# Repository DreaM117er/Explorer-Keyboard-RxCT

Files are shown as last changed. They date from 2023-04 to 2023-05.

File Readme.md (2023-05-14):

# Explorer Keyboard RxCT 探索者1號

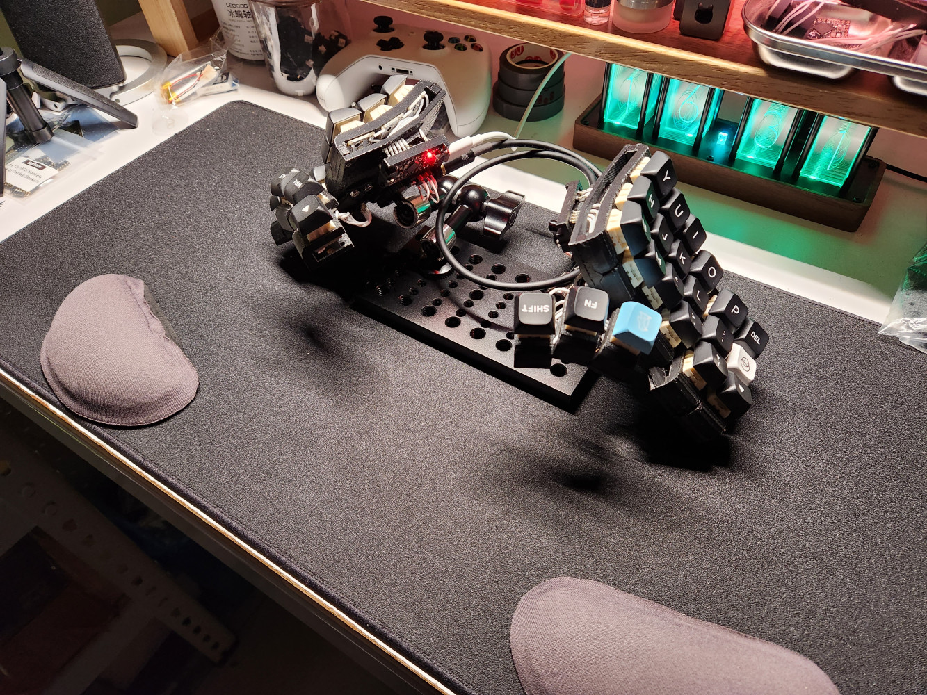
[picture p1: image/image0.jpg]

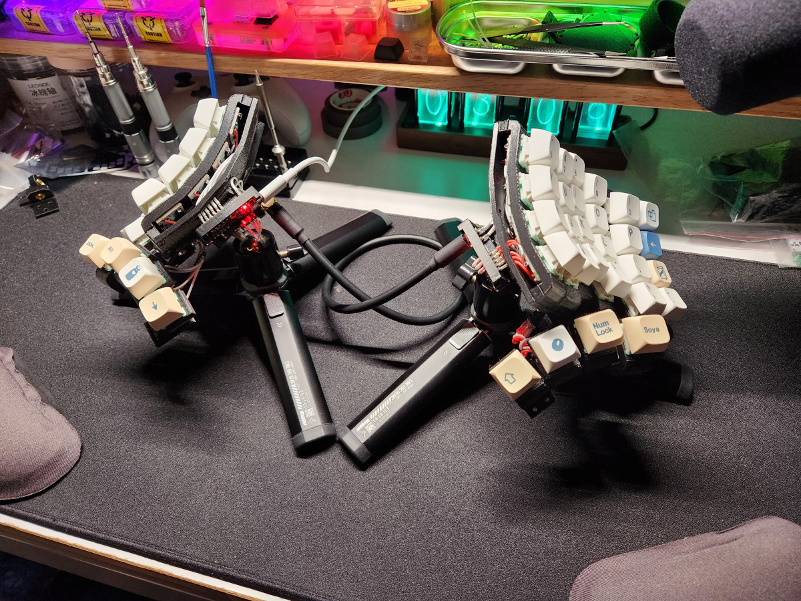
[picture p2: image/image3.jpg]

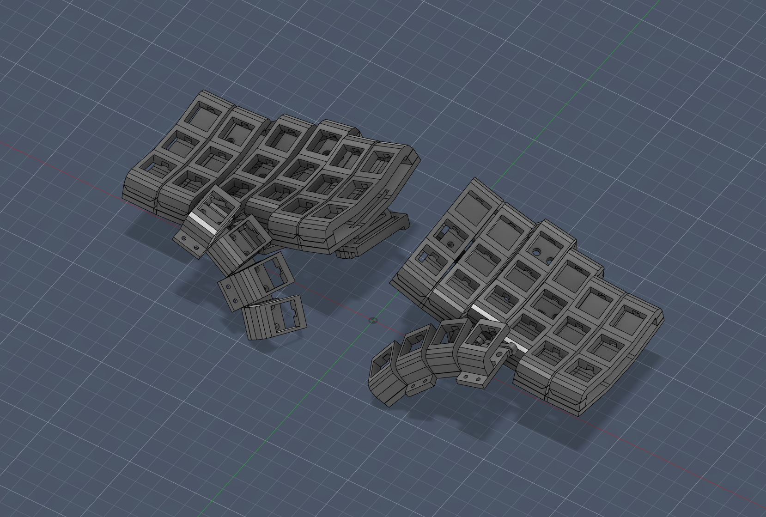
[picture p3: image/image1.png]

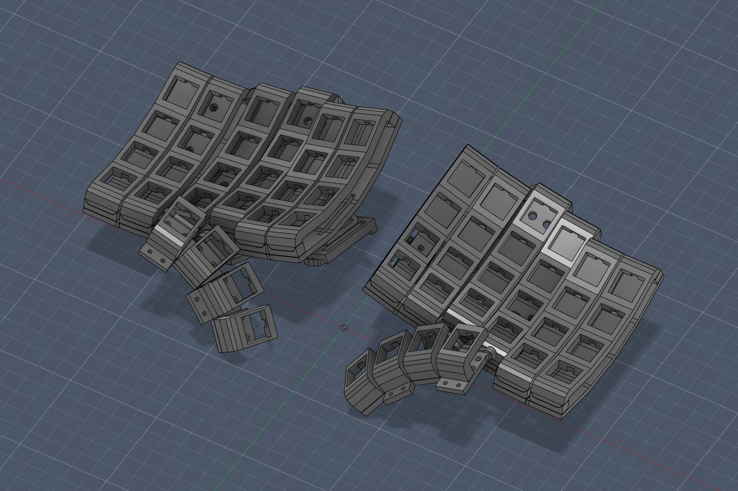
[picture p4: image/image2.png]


## 簡介

RxCT是基於[Dactyl Manuform](https://github.com/abstracthat/dactyl-manuform)家族中的5x6、[Skeleton Edition](https://github.com/atsuyuki/dactyl-manuform-skeleton-edition-4x5)及[Bastardkb TBKmini](https://github.com/Bastardkb/TBK-Mini)這三把分離式鍵盤設計，其特點在於使用相機雲台作為主要固定方式，以3x5及4x5為鍵盤主配列，可向外側拓展1排按鍵，將鍵盤配列變更為3x6及4x6；拇指區基礎為1-4顆按鍵設計，可依據底板連接器橋接拇指區的每顆按鍵，再根據連接主鍵盤的基座，微調拇指區角度的分離式機械鍵盤。

## 特色

- 直列定位板、拇指按鍵模組化設計
- 可調整整體角度的拇指區
- 拇指最外側及最內側定位板可2檔微調
- 主要雲台安裝位於底殼，可外掛插件將雲台安裝在前端

## 組裝及操作說明

- [組裝說明書](guide.md) 
- [操作說明書](manual.md)
- 無線安裝說明（開發中）

## 構造

- 底殼（3x5及4x5基礎大小）
- 拓展板（3x1及4x1）
- 框架（3x5、4x5及拓展1x1）
- 直列定位板（3x1及4x1）
- 拇指區基座
- 拇指定位板
- 拇指底板（2片可接基座、2片純拓展）
- 拇指底板連接器
- 主控座（可安裝TRRS、純MCU）
- 電池倉（2050規格聚合物鋰電池，3種厚度）
- 前方雲台插件

## 構造圖

- 底殼、拓展板
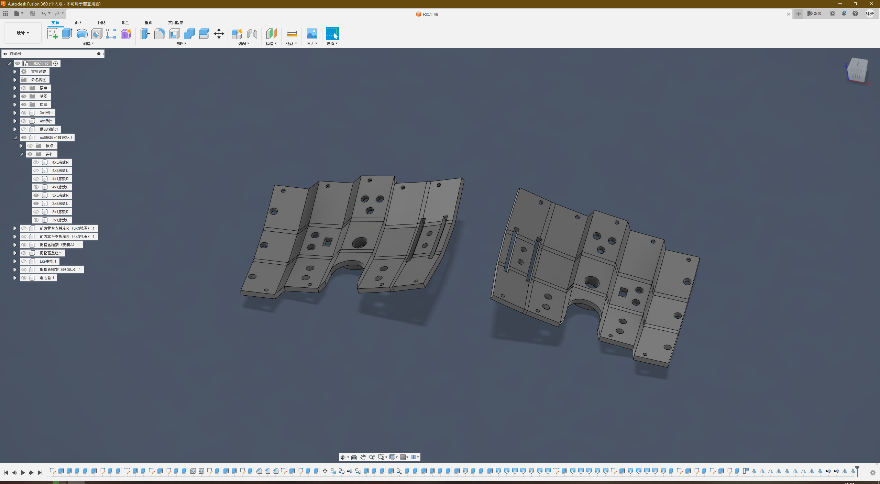
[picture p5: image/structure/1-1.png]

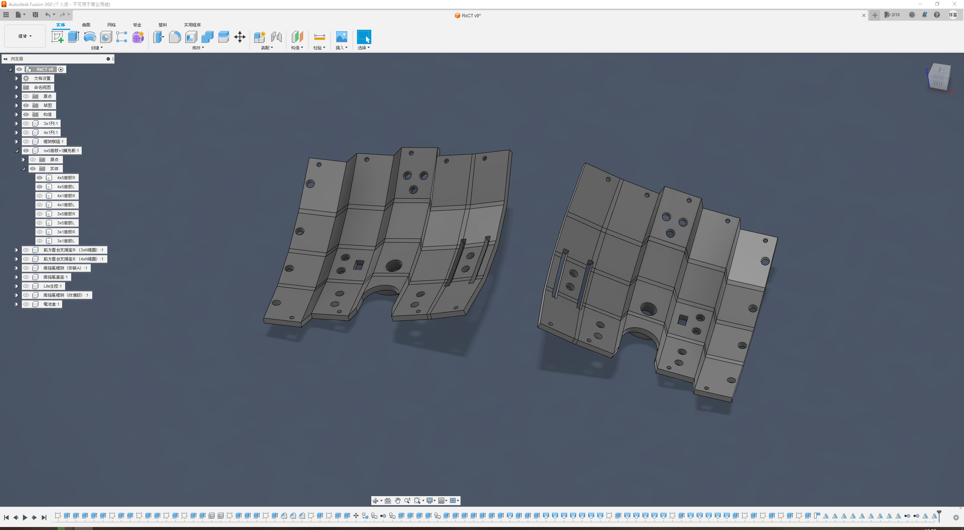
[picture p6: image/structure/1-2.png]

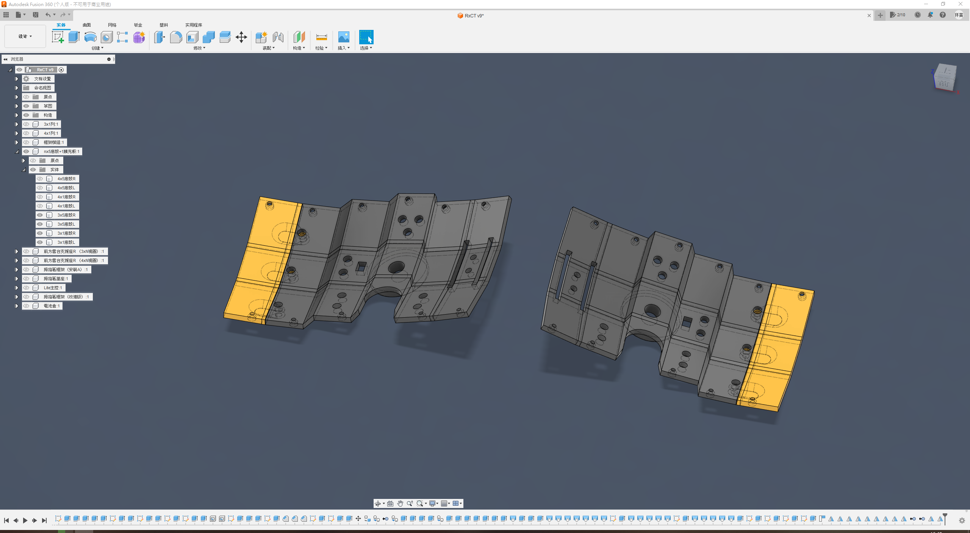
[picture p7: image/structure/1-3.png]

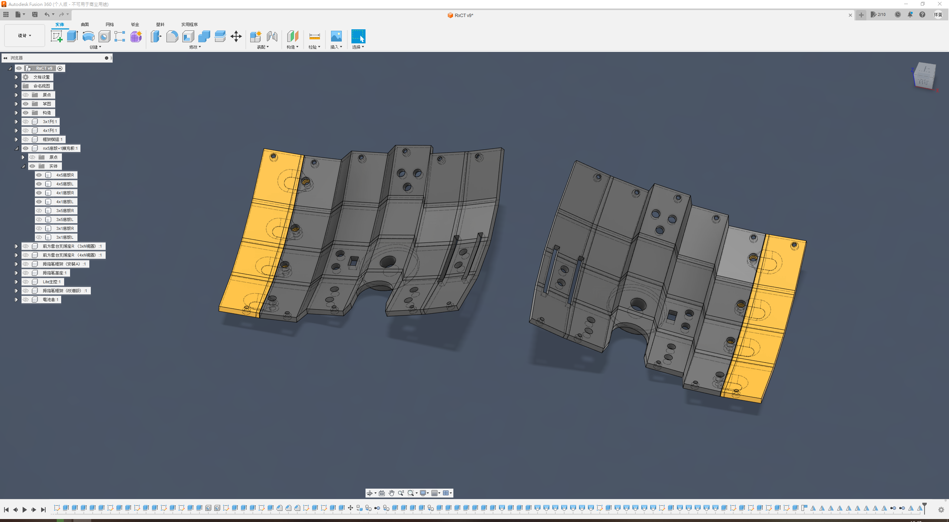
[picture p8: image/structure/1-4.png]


- 框架
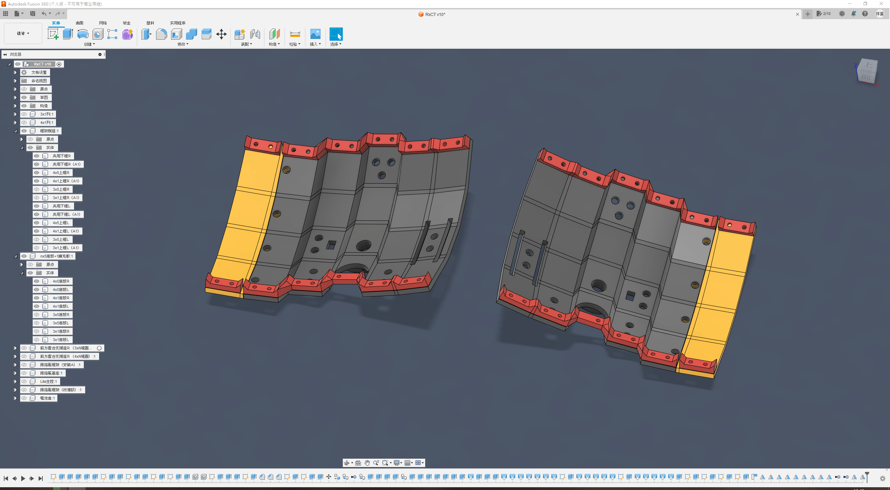
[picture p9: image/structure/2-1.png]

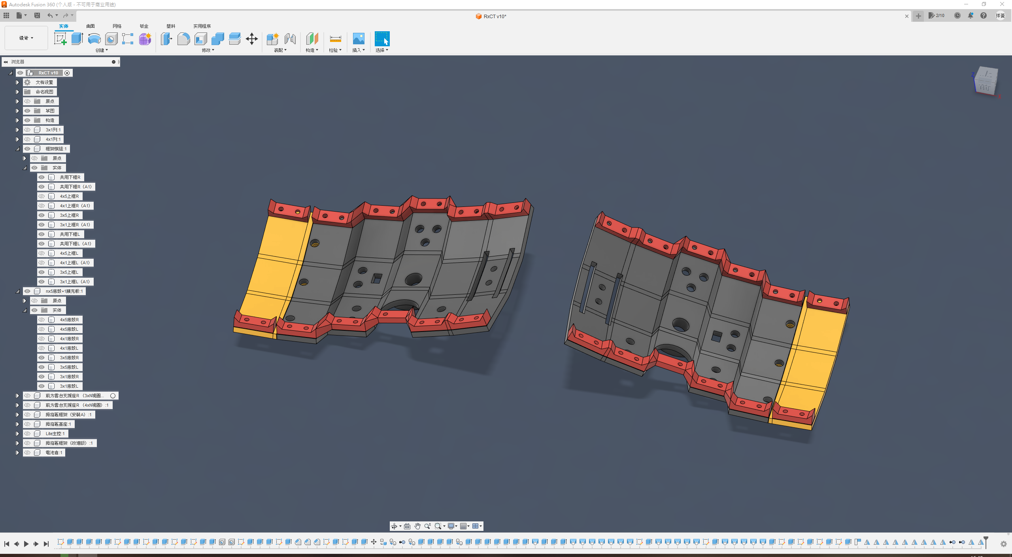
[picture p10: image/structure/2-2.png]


- 直列定位板
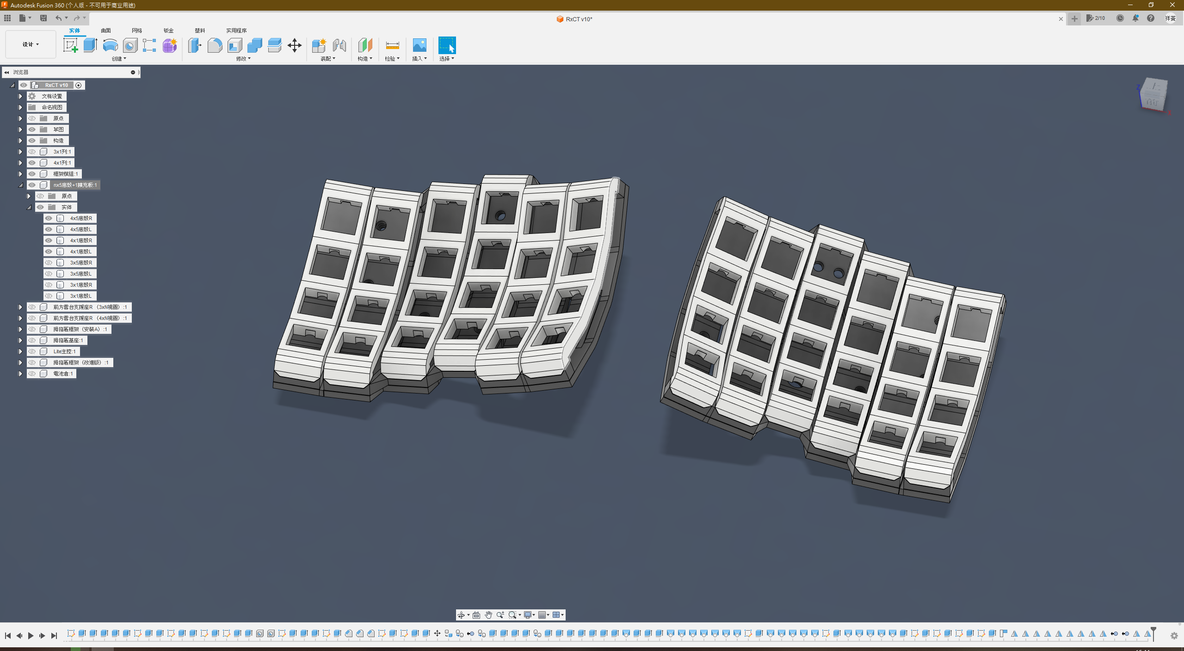
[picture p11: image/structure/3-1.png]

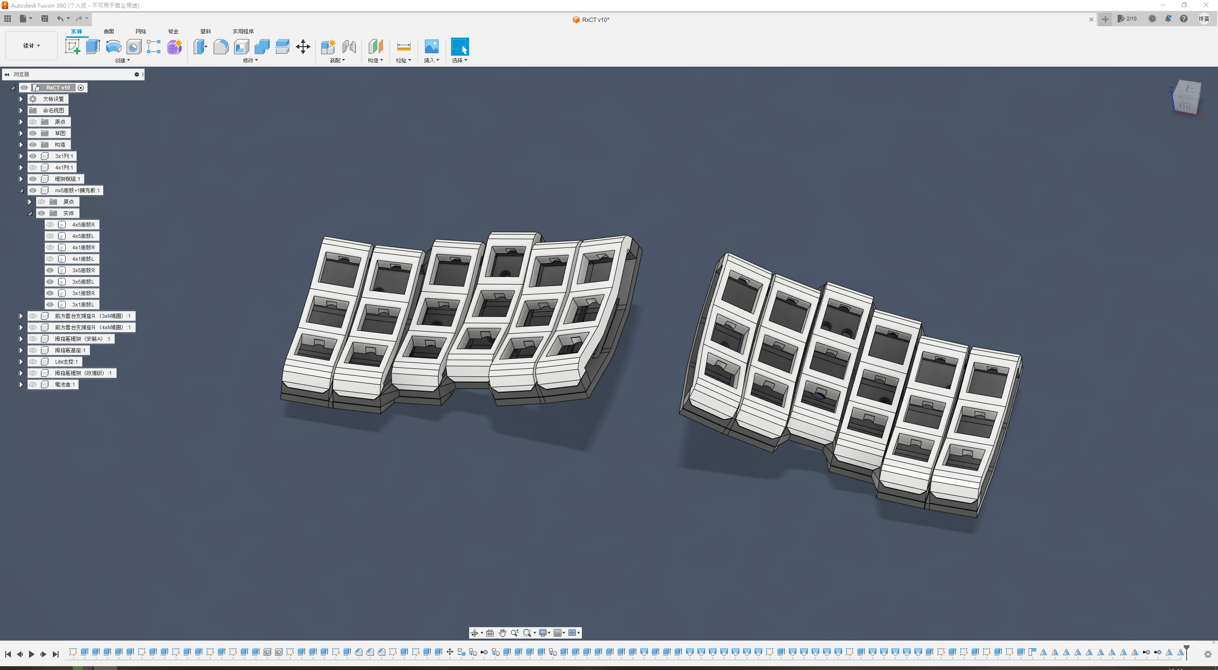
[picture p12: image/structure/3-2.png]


- 拇指區基座
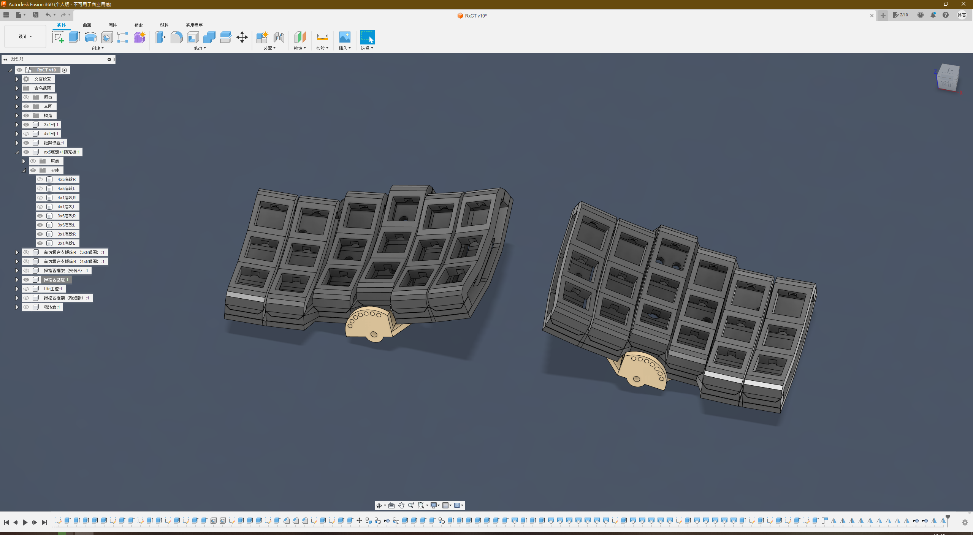
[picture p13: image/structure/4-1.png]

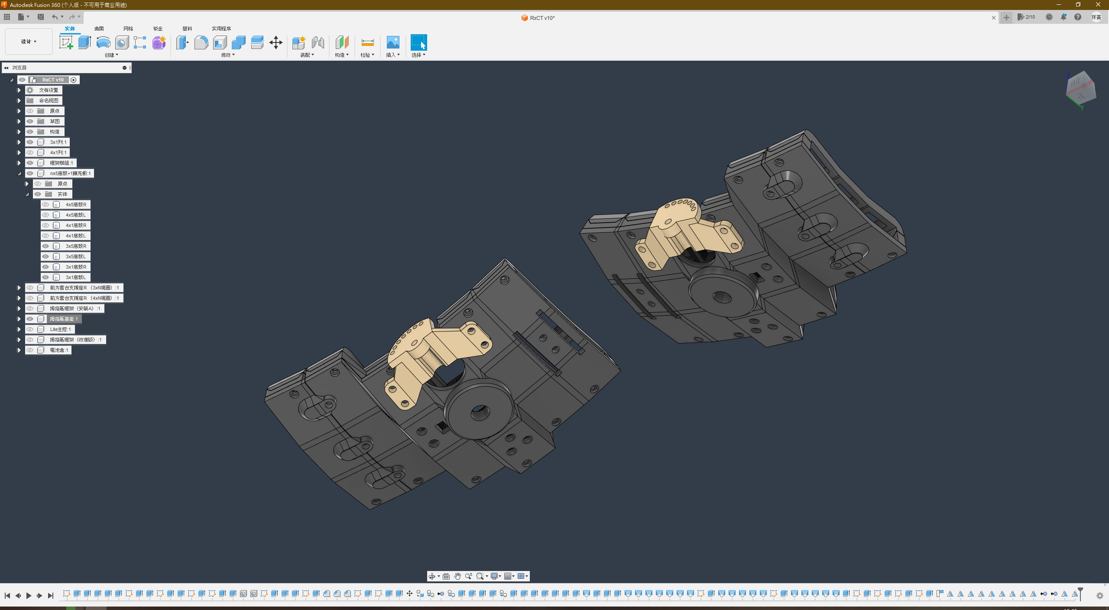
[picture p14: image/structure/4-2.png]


- 拇指定位板、拇指底板、連接器
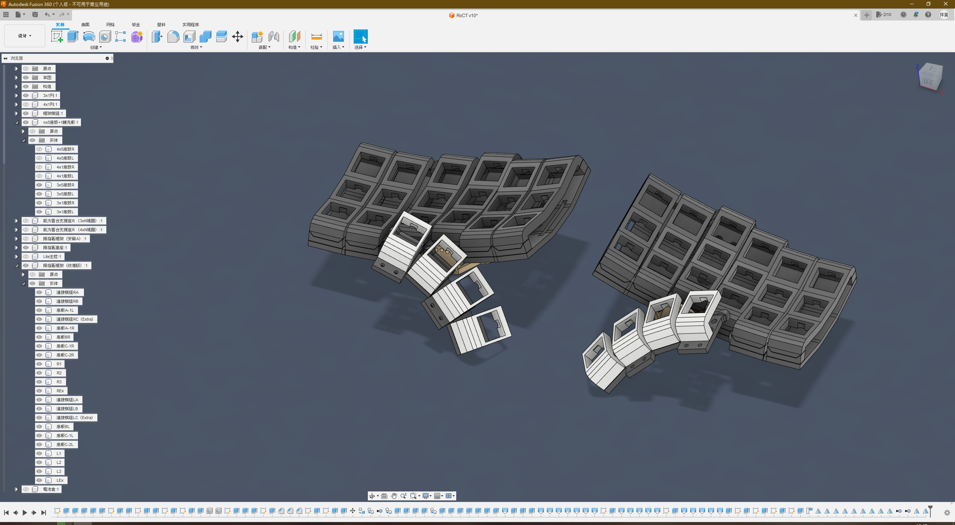
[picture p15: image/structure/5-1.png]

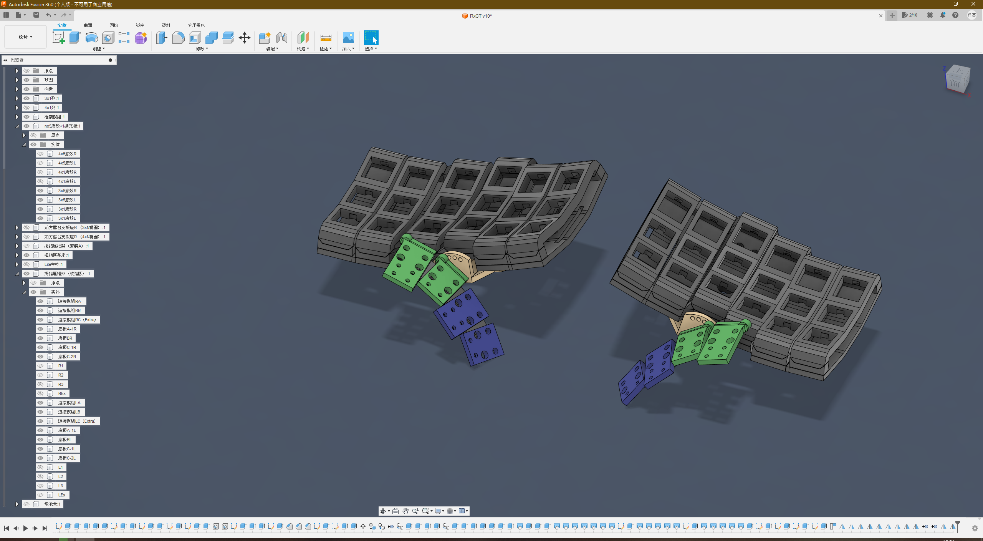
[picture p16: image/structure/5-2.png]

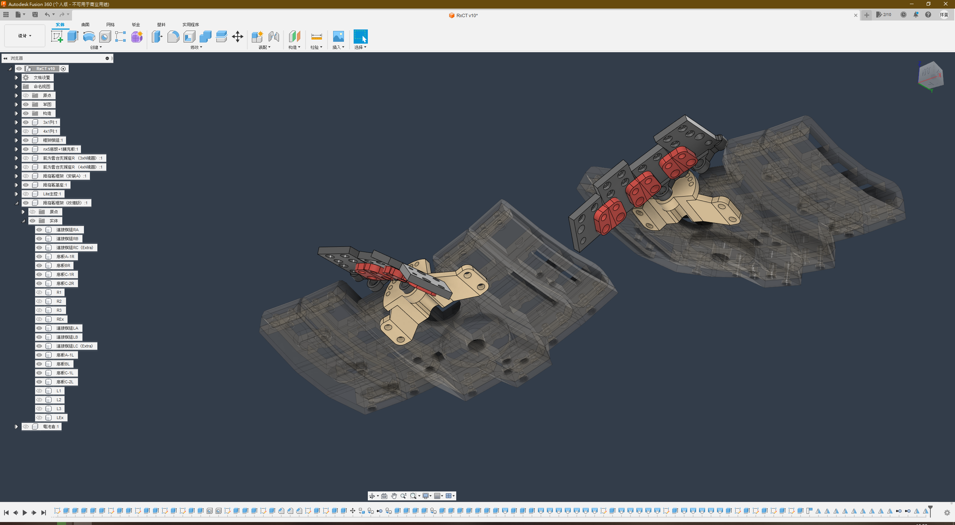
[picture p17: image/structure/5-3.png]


- 主控座、電池倉
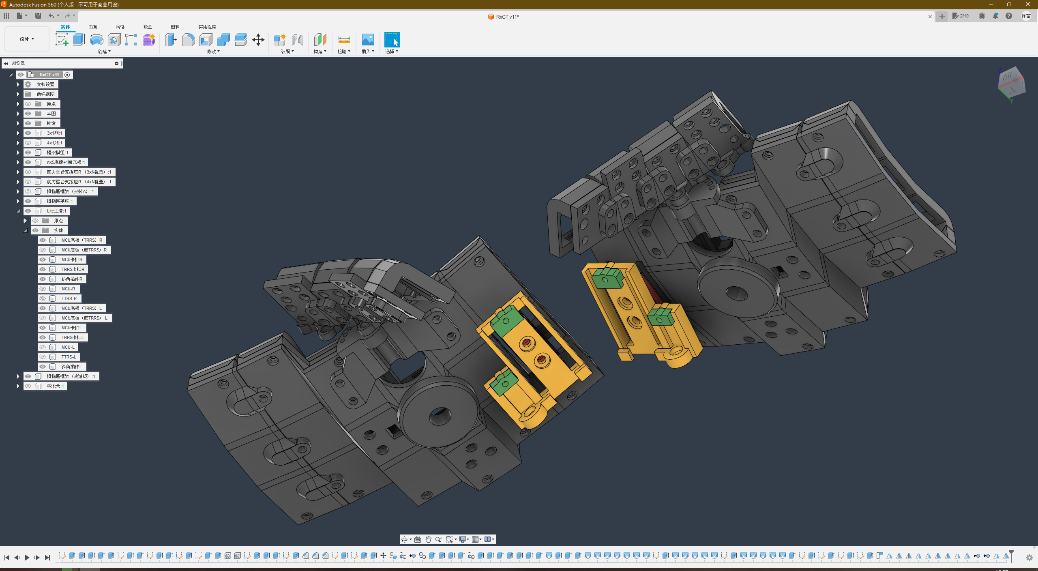
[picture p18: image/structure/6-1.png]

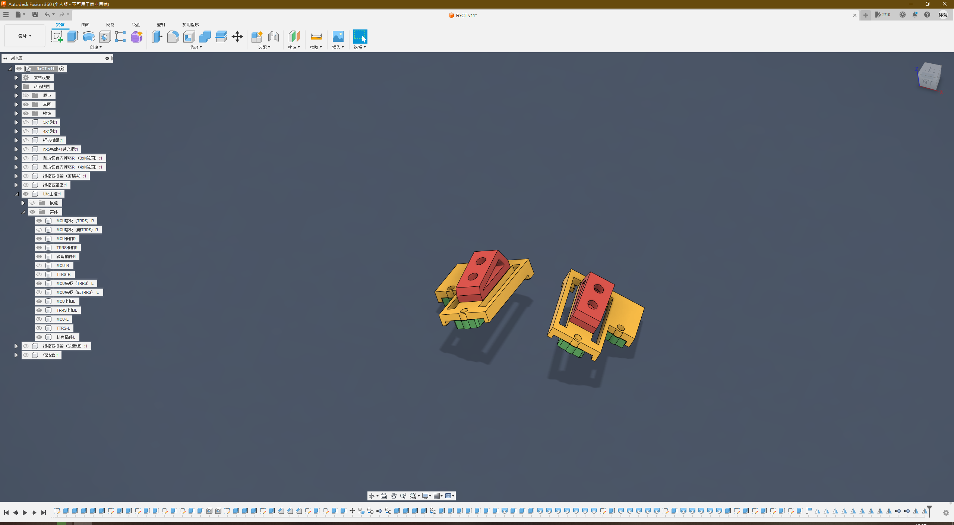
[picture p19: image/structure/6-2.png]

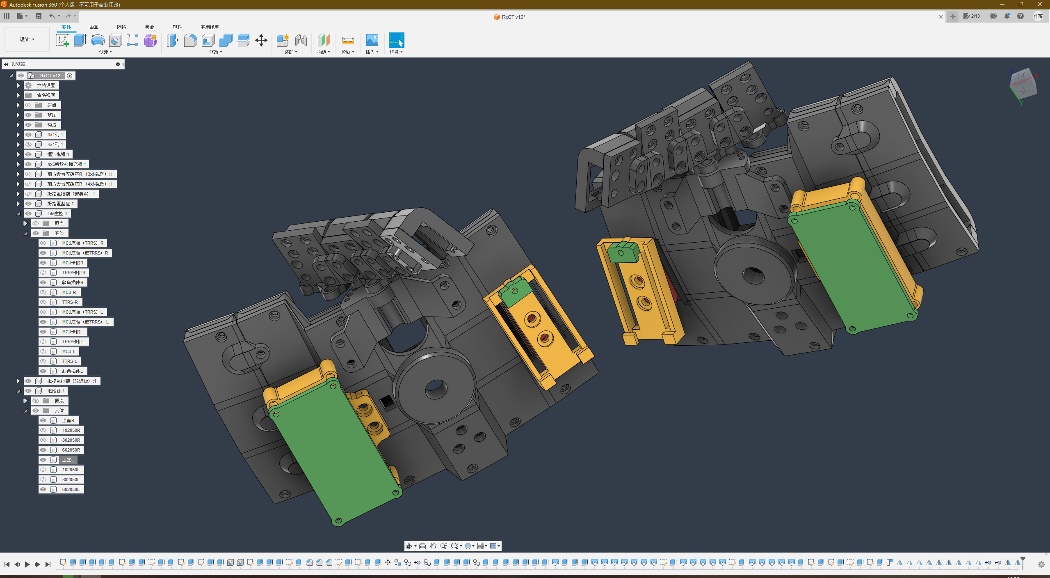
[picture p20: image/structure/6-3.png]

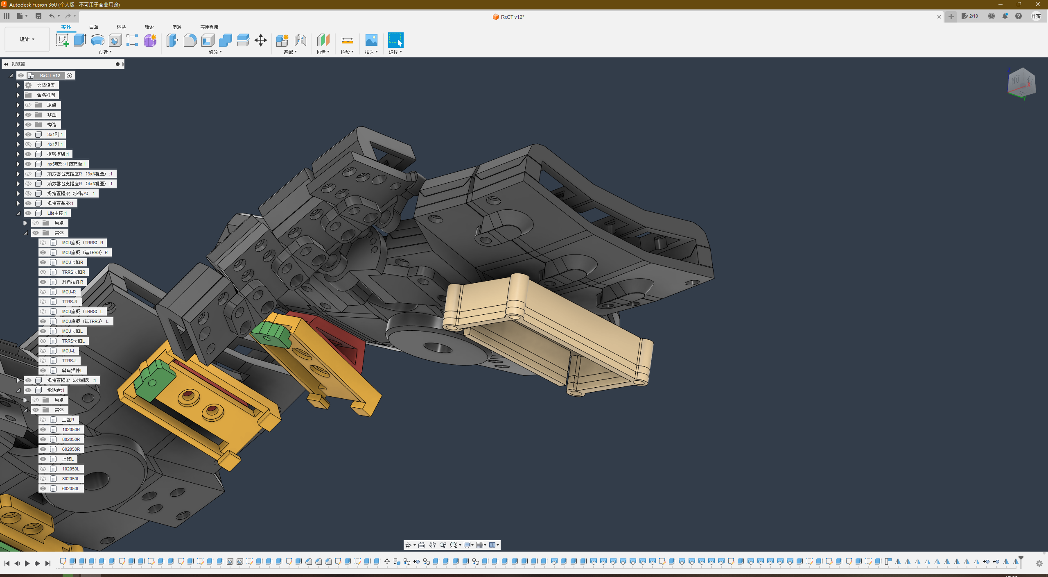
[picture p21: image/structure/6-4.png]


- 前方雲台插件
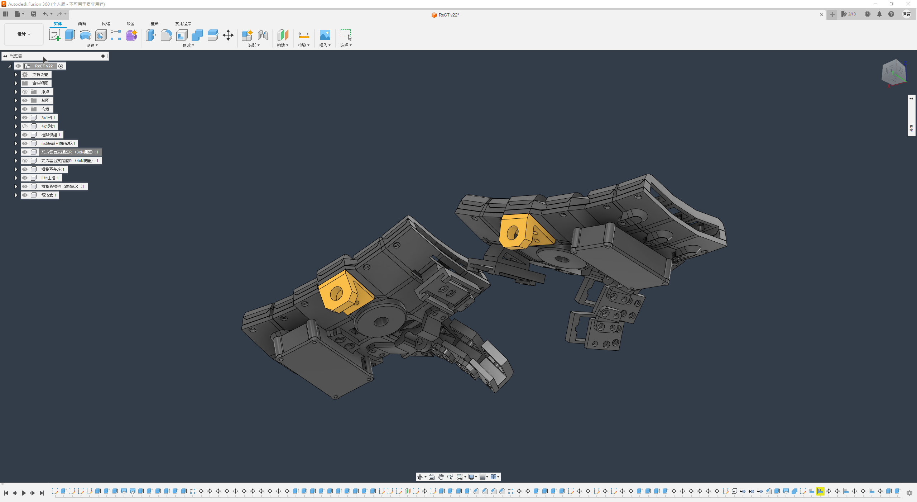
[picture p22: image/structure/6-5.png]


## 特別感謝

- [Pragmatic務實鍵盤](https://github.com/jamessa/Pragmatic)及開發者[James Sa](https://github.com/jamessa)，在3D設計、3D列印、韌體代碼、[人體工學邏輯](https://www.youtube.com/watch?v=p7gZdOTpbP8)上的指導。
- [務實鍵盤官方網站](https://www.pragmatic.com.tw/)
- [Bastardkb](https://bastardkb.com/?fbclid=IwAR0HTUxLdHe8ZL2sCDtqDt270YRag5GlEKGHjyKge5UxckXjq_M7VrpKhu0) [TBKmini](https://bastardkb.com/product/tbk-mini-kit/)、[Dactyl Manuform](https://github.com/abstracthat/dactyl-manuform) 5x6、[Dactyl Manuform Skeleton Edition](https://github.com/atsuyuki/dactyl-manuform-skeleton-edition-4x5)，沒有接觸到你們，也不會有探索者的誕生。
- [KBDnews](https://kbd.news/Explorer-RxCT-1994.html)
- [開發日誌](log.md)

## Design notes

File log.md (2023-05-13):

# 開發日誌

## 開發歷史

- 2022.12.26 正式組裝第一把TBKmini。
- 2023.01.09 正式完成Dactyl Manuform 5x6。
- 2023.01.16 完成第二把TBKmini（完全手拉矩陣），改寫QMK韌體。
- 2023.01.26 正式安裝[Fusion360](https://www.autodesk.com/products/fusion-360/overview?term=1-YEAR&tab=subscription)在個人電腦上。
- 2023.01.31 請James列印的Skeleton Edition入手。
- 2023.02.11 第一款失敗模型設計成品入手。
- 2023.02.28 第二款失敗模型設計成品入手，到03.07才知道它也是失敗模型。
- 2023.03.08 探索者第一版雛形成品完成。
- 2023.03.14 探索者第二版模型完成。
- 2023.03.22 探索者Prototype單手模型完成。
- 2023.04.01 探索者正式命名為系列，3x6+3鍵盤完成、測試。
- 2023.04.15 正式命名RxCT為探索者1號。
- 2023.04.23 探索者1號檔案Github正式開源。
- 2023.04.24 探索者1號登上[KBDNews](https://kbd.news/Explorer-RxCT-1994.html)。
- 2023.05.06 支援探索者1號的[VIAL](https://get.vial.today/)韌體完工。
- 2023.05.10 探索者1號的[韌體](https://github.com/DreaM117er/Explorer-Keyboard-RxCT/releases)正式發佈。
- 2023.05.14 探索者1號4x6+4鍵盤完成、測試。

## 開發心得

探索者1號的開發大約花了一個半至兩個月的時間，很多人會認為一把這樣需要調整這麼多參數的分離式機械鍵盤需要花相當多的時間去完成，通常大部分人認知是這樣沒有錯。但這真的是事實，我在2023年1月26日正式在我個人的電腦上安裝[Fusion360](https://www.autodesk.com/products/fusion-360/overview?term=1-YEAR&tab=subscription)，安裝AutoDesk這款工程3D軟體的時候，我連3D繪圖都不了解。

沒有錯，我是個3D繪圖基礎都沒有的新手，對於自己設計分離式鍵盤來說，這毫無疑問是相當大地挑戰，前前後後自己找了網路資源慢慢學習，學了一個步驟之後就直接開軟體實作，實作的對象就直接是鍵盤本體。

真的要說我失敗了幾次嘛... 也有20次以上了，實際加上James協助我做3D列印的服務的時候都要謹慎，不是所有設計出來的東西都是可以100%列印成功的，即便成功好了，實際模型是不是可以運作也是一大課題；嚴格來說James協助我做3D列印服務，我們雙方也是買賣關係，僅在設計鍵盤方面有著相同的背景及興趣，我真的很感謝他，讓我這個瘋子能夠順利地完成這把鍵盤。

## 設計理念

從我開始入手使用分離式人體工學鍵盤後，就發現每把鍵盤都有1個到2個我覺得是缺點的地方，打個比方：

- [Corne](https://github.com/foostan/crkbd)的拇指區，最內側的按鍵真的是相當地難按，而且相當不舒適。
- [TBKmini](https://github.com/Bastardkb/TBK-Mini)則是中指太過下凹，導致我在移動食指中指的時候非常容易卡到鍵帽。
- [TBKmini](https://github.com/Bastardkb/TBK-Mini)後來經過James的指導後發現拇指區正常擺放時也會有傷害到手指的疑慮，觀察過後真的是如此。
- [Skeleton Edition](https://github.com/atsuyuki/dactyl-manuform-skeleton-edition-4x5)原本會是我的下一把鍵盤，但礙於沒有3x6+3的配列，也就成為我開始設計鍵盤的主因之一。
- [Dactyl Manuform](https://github.com/abstracthat/dactyl-manuform)則是體積太大，底座太高，不然它真的相當舒適。

綜合起來歸納出來幾點是我想改進的：

- 長得像TBKmini的3x6+3，合計42鍵的鍵盤。
- 根據使用鍵盤時手指正常移動的軌跡後發現需要讓中指區跟食指、無名指區域齊平。

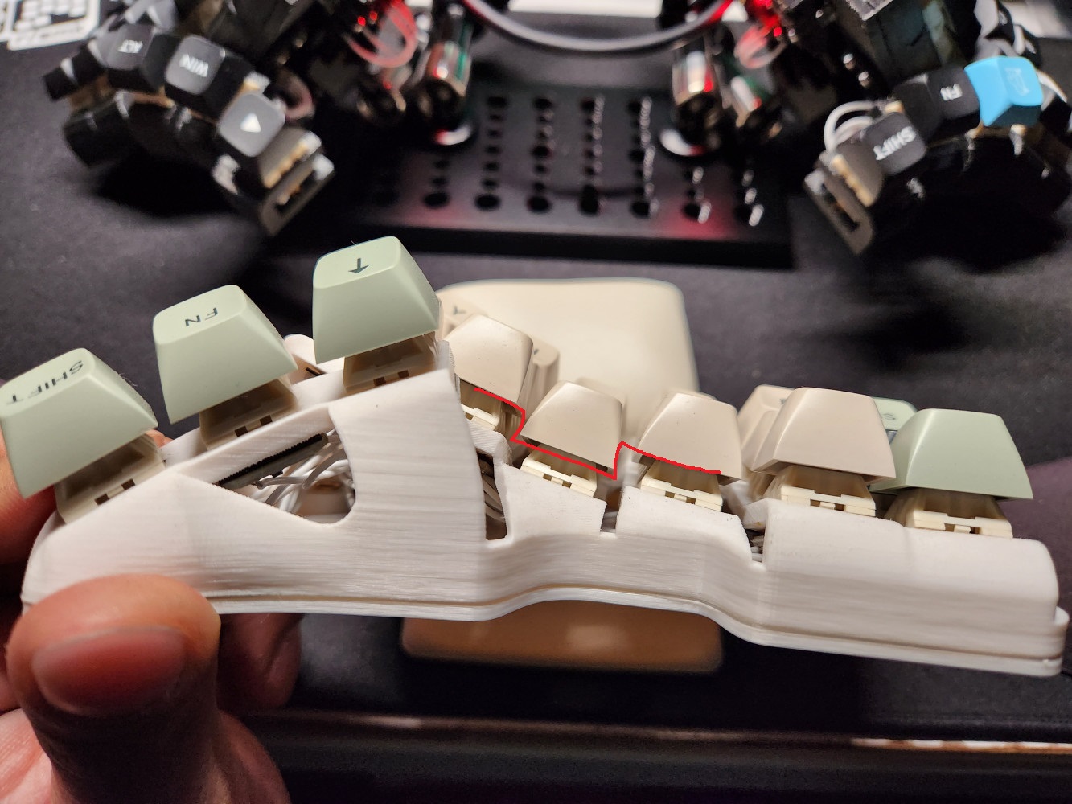
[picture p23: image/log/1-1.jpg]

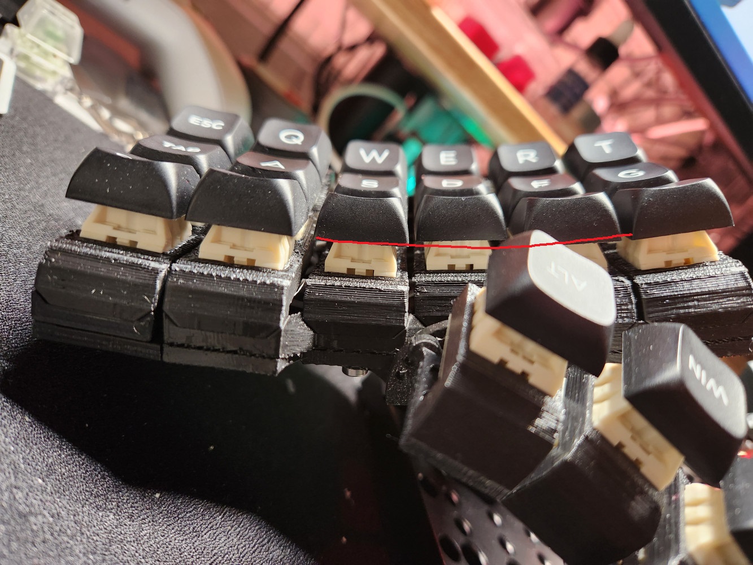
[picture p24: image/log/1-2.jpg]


- 拇指區要能夠遵守正常擺放及使用不會把筋爆出來的原則。

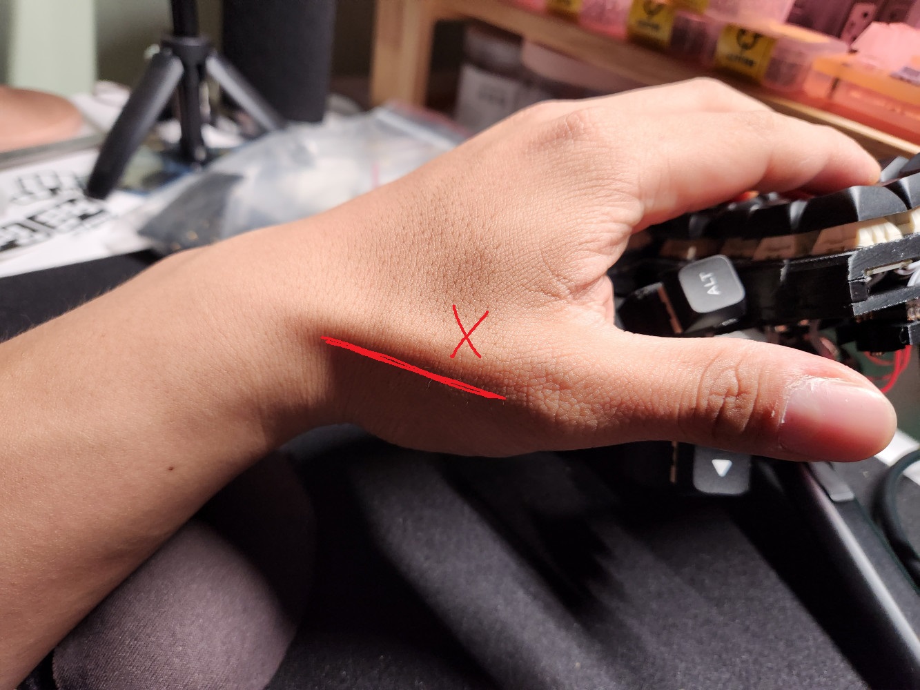
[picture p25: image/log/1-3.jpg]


- 拇指區要能夠微調角度。
- 長得要跟[Skeleton Edition](https://github.com/atsuyuki/dactyl-manuform-skeleton-edition-4x5)一樣Cyberpunk。

## 設計過程

起初在Facebook社團[Mechanical Keyboards USA](https://www.facebook.com/groups/mechanicalkeyboardsusa)的一位老哥在我的文章底下留言，說自己嘗試組裝Skeleton Edition失敗，於是問了怎麼個失敗法？結果對方也沒有回覆我，一直讓我通靈解決問題，但同時我也被這把鍵盤那Cyberpunk的外觀給煞到了，當時又處於[EdgeRunners](https://www.cyberpunk.net/zh-tw/edgerunners)流行期間，我當時所有的Fusion360的設計都有那個味道在...

第一次設計出來的模型長的跟Skeleton Edition非常相似，底座更改為球體，走線都走在球體內，但我沒有想到3D列印的公差，於是整個模型呈現一個大失敗，熱壓螺母的定位孔也直接崩解，不鏽鋼柱由於沒有計算到公差而無法順利的安裝，甚至有一處直接被我壓到裂開；定位板的部分則是沒有計算好按鍵跟按鍵之間的距離，導致安裝好鍵帽之後直接卡死。最後詢問James大致上3D列印的公差後，正式開始了第二次設計。

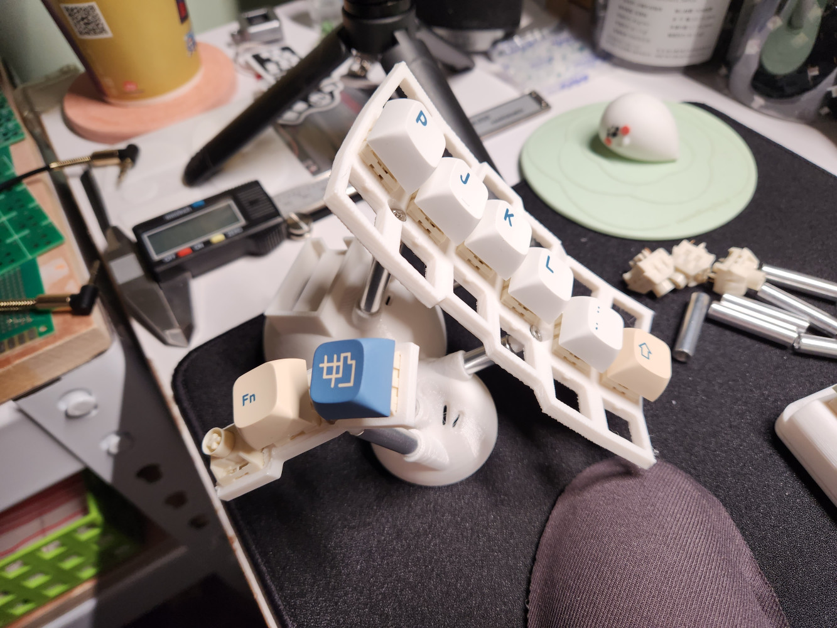
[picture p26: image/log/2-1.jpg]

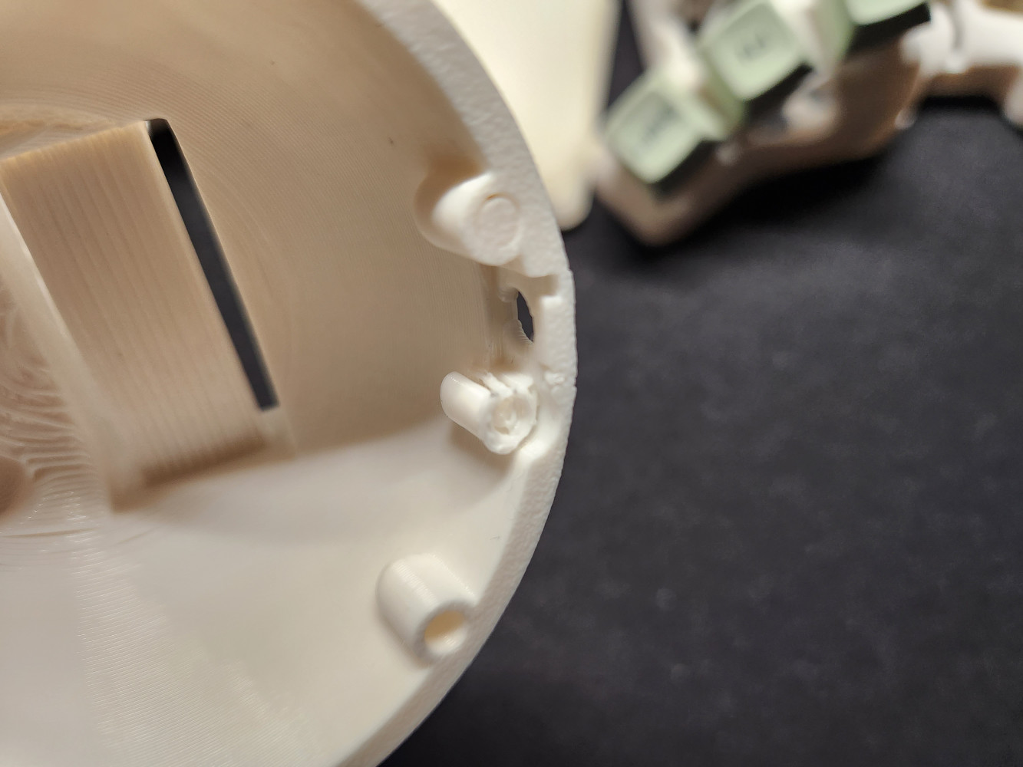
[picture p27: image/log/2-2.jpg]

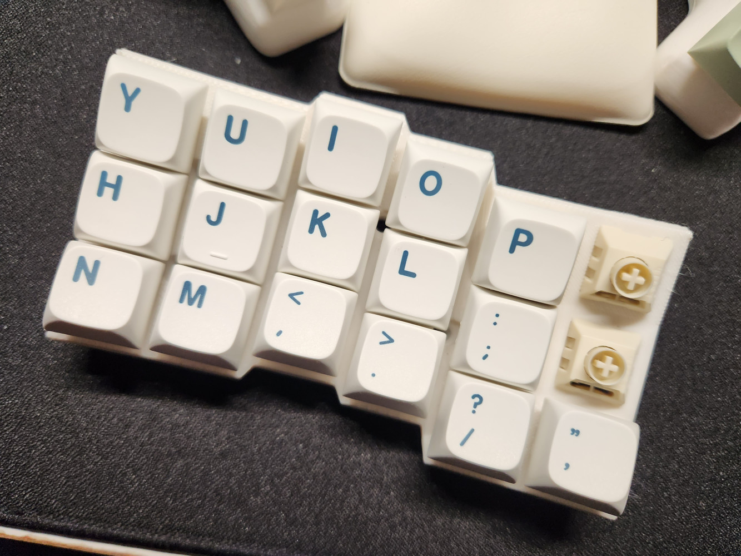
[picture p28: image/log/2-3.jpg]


我在第一次的模型設計後就有發現，拇指區相當難設計，主鍵區真的還好，我很早就將模型設計出來了，而且有很多不同的構想。有第一次的失敗後就決定慢慢來，設計循序漸進地先將主鍵區的公差搞定，結果左右距離過遠（汗），但確實手感相當的好，於是就依據這個主鍵區模型開始後續探索者的設計...

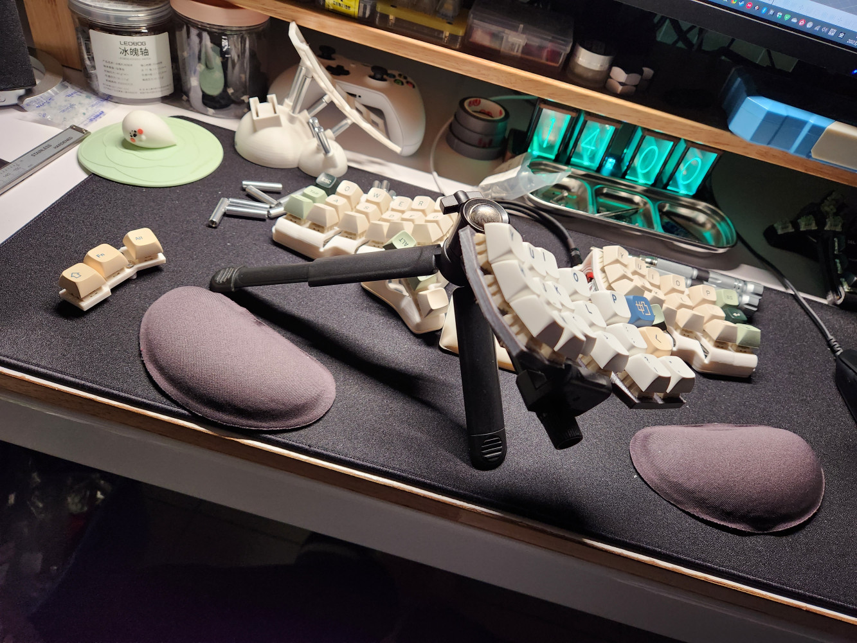
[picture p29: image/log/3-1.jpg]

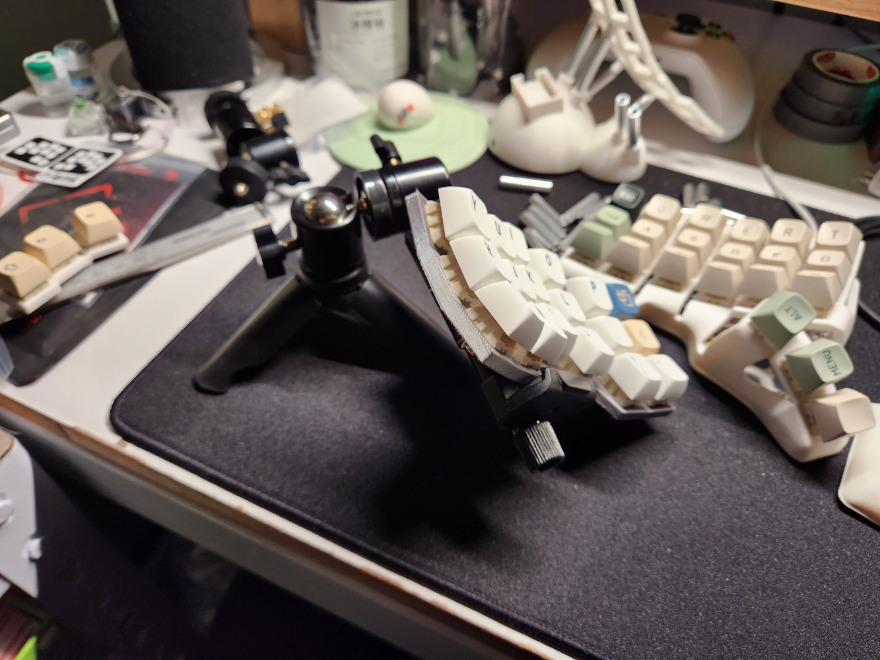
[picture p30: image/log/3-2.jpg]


為什麼會想到雲台？有一天我在整理收納空間的時候翻到之前擺在一旁沒有用到的手機支架，支架上剛好有一個雲台，就這樣把構想告訴James後，第一個探索者的模型誕生了。

第一版的雛形是將前方雲台座整跟底部雲台座一體成形，但後來體積實在是太大，鍵盤整體高度太過，於是將這個設計捨棄掉，另闢一個新的設計。

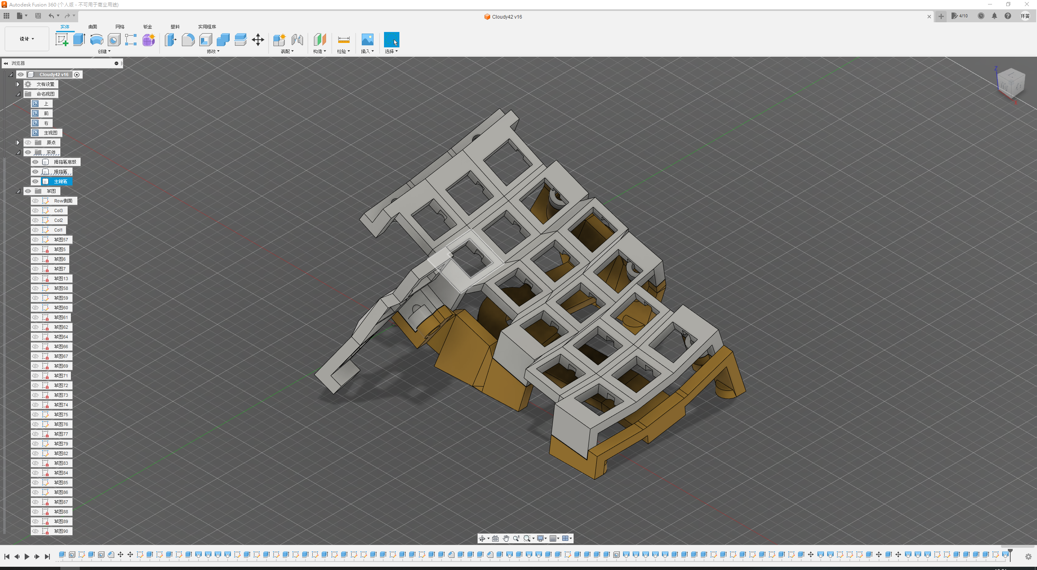
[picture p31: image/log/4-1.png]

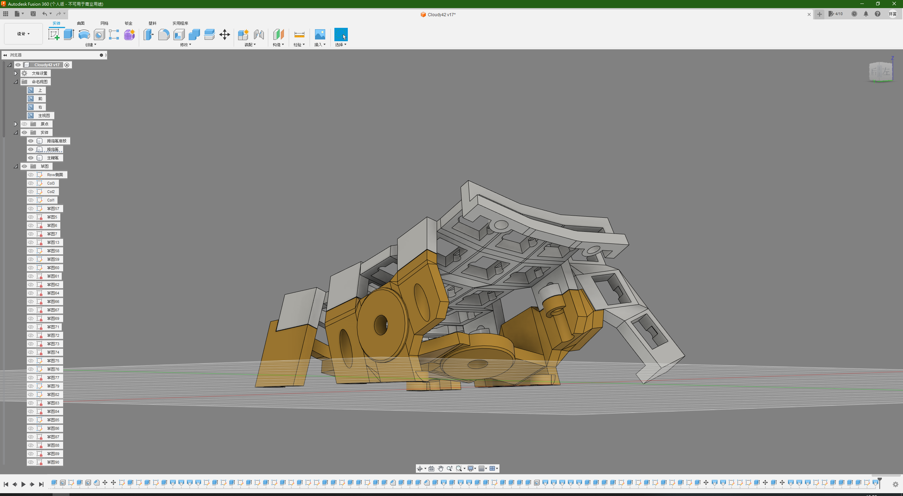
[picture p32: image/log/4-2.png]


第二版將底部雲台座整個分離，原先是想要將這個可以分離的雲台座卸下安裝在前端，好達成壓低鍵盤厚度的構想。但實際設計好後才發現不如一開始就將雲台設計在底部，用外掛插件的形式將雲台座設計在前端。

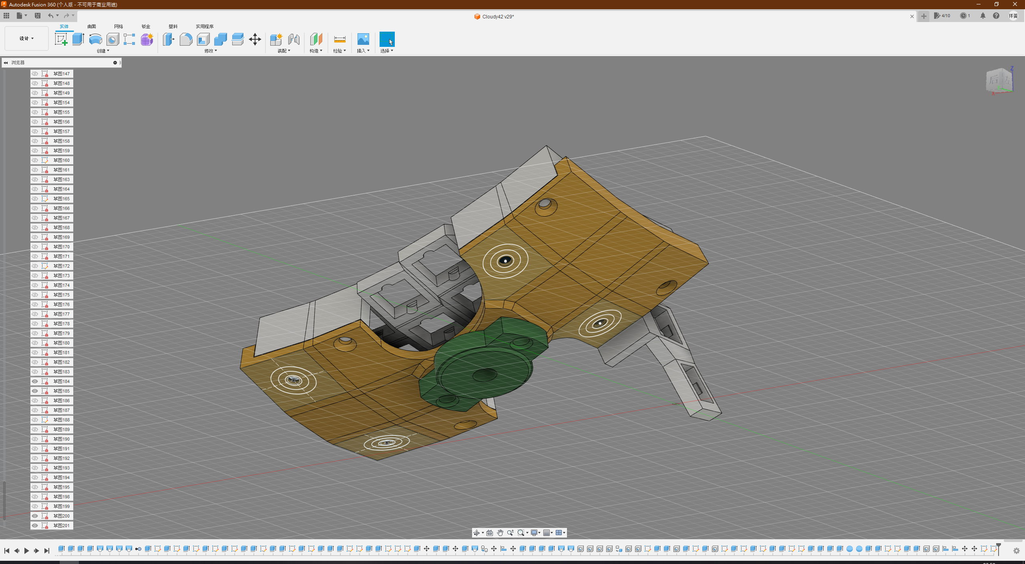
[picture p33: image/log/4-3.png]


還在思索可以怎麼設計的時候，眼睛盯著當時擺在我眼前的TBKmini，於是就開始觀察它，看著我覺得一直是缺點的中指凹陷處、開槽直接裸露裡面內部走線的洞口，最後看到按鍵跟按鍵中間的開槽處，於是有了一個很特別的想法：

"那不如就把這個直列部分切成6等份，做一個模組化的鍵盤？"

這就是RxCT模組化的起源，後續設計的時候一直朝著這個構想前進，有什麼遇到困難的地方，就是一個轉念讓自己好好地思考模組化可以怎麼設計。

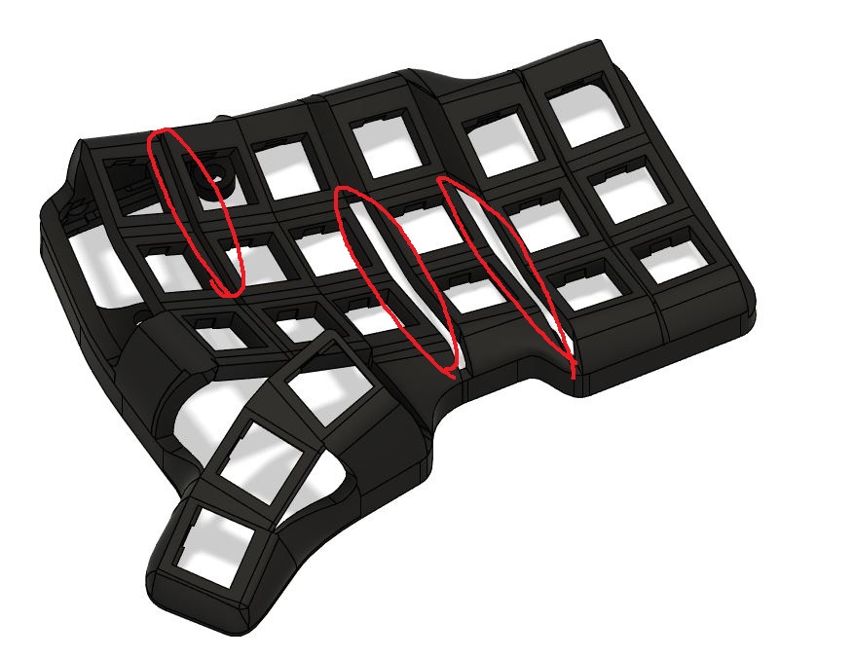
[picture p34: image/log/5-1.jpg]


底殼設計好後，依然卡在最難設計的拇指區，一開始也是仿照主鍵盤區塊設計，但實際收到幾次的模型後James都有發現框架過於脆弱的問題，它很容易斷裂。於是這兩個大問題就花了不少時間去重新設計，主框架太脆弱的問題後來是將框架用部分放樣做加固；拇指區比較特別，我將基座的雛形建制出來後，拇指按鍵設計好再來設計，但不管我怎麼移動拇指區的底板就是哪裡不太對、用框架架設拇指定位板也不對、旋轉角度也不太對... 

兩天之後我拉了一個複製模型出來，左右微調15度，上下12度，意外建立了一個很漂亮的角度，也就這麼採用了；再來就是思考是不是要將拇指區底板用放樣的方式連接起來？然後腦裡又嘣出一個想法：

"如果不要放樣接起來的話，那就用連接器連接，按鍵統統分開來設計好了。"

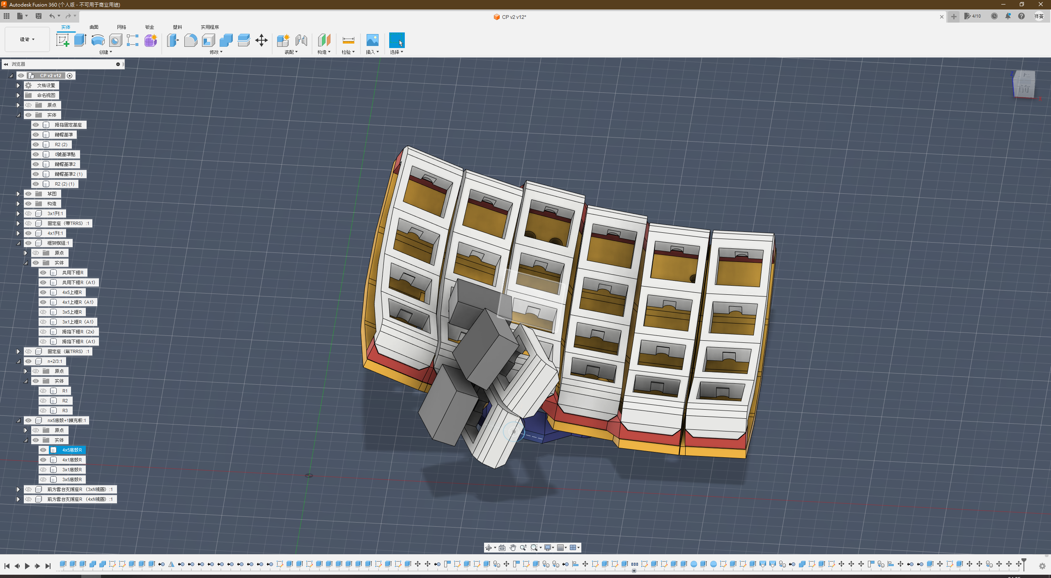
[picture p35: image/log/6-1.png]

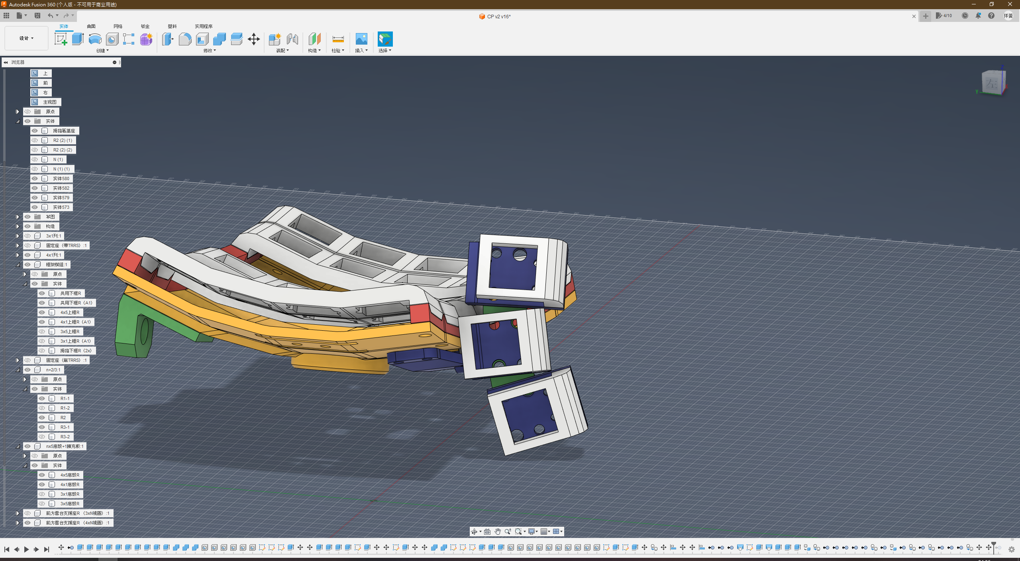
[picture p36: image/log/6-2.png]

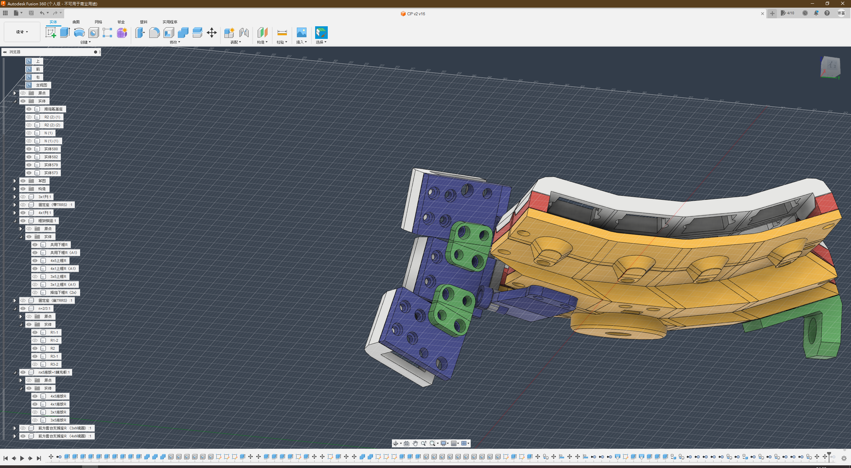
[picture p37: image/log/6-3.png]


很多種的意外，導致這把鍵盤有很多人覺得不可思議的設計，我相信能夠設計出來就是我自己的創意發想，這點毋庸置疑。

這就是探索者1號的設計過程，很奇怪但也很務實，完整呈現給能夠看到這裡的人，如果你也有這樣卡住無法設計的時候，不妨想想自己最初是靠著什麼理念在設計。想一下，或許它很簡單，只是你沒有發現而已。

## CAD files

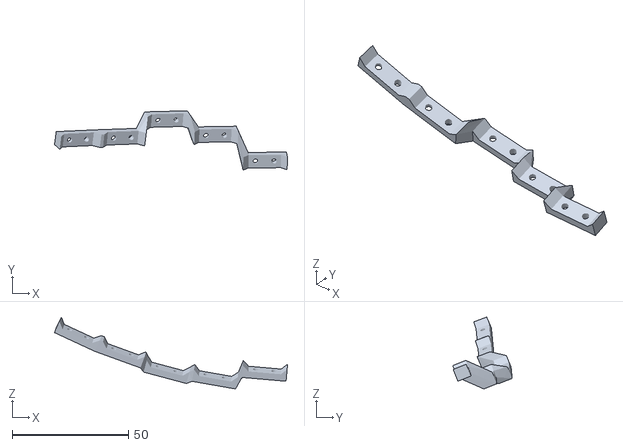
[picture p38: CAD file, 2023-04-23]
files/right-4x5 upper main frame.stl
100.0 x 25.5 x 30.9

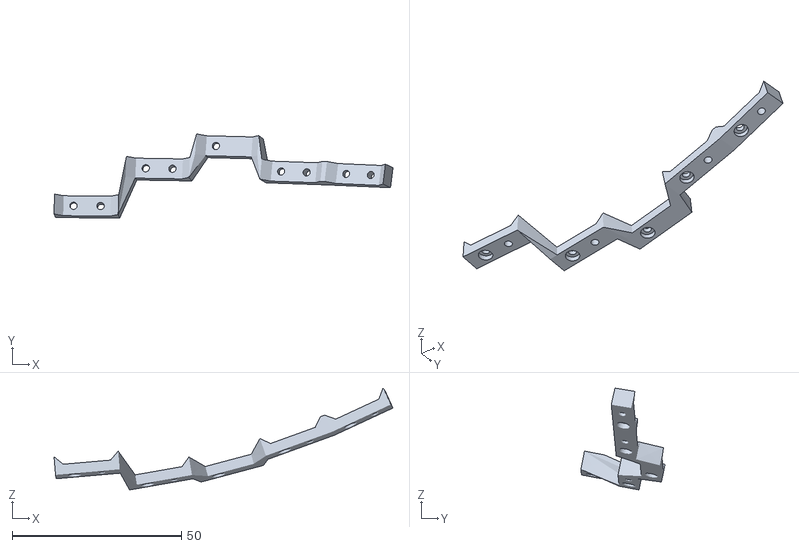
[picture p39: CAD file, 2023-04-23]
files/left-lower main frame.stl
100.0 x 24.8 x 30.1

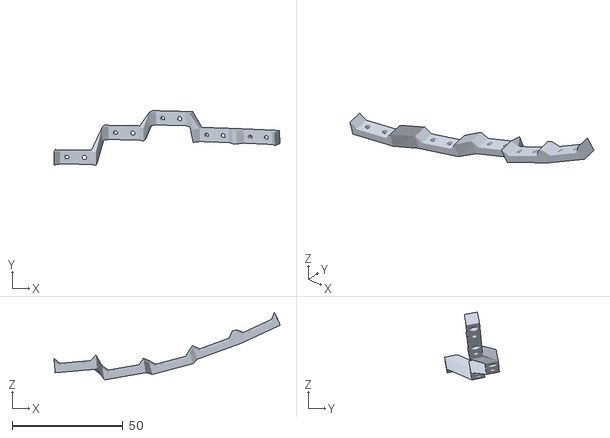
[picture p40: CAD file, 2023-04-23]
files/left-3x5 upper main frame.stl
102.1 x 24.8 x 30.7

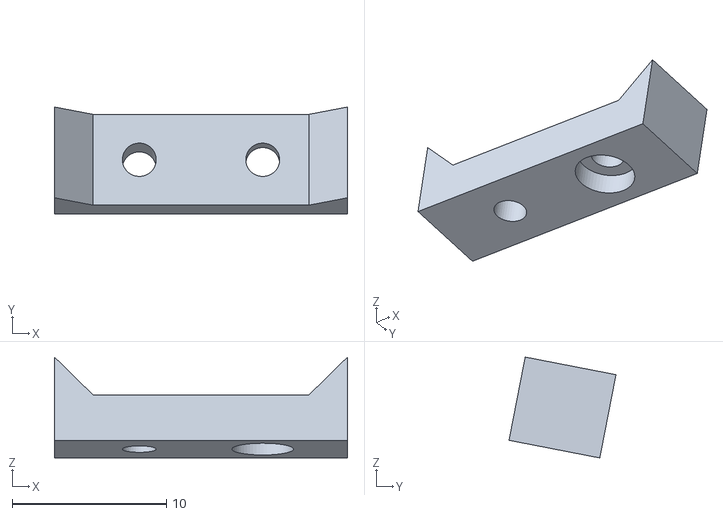
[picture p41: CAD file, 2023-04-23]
files/x1-main frame.stl
19.0 x 6.94 x 6.54

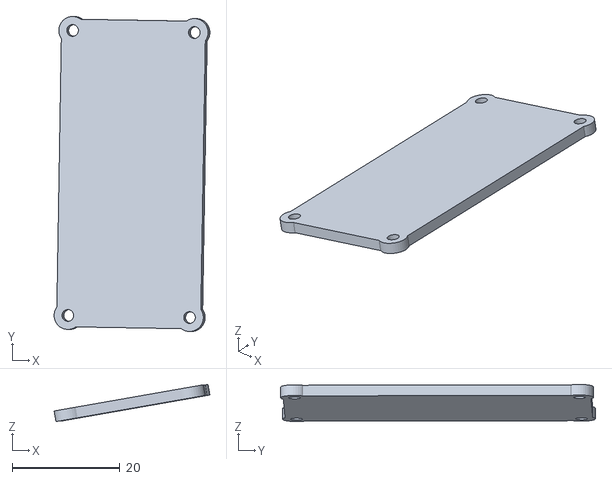
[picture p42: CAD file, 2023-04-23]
files/battery/left-case cover.stl
29.0 x 58.5 x 6.91

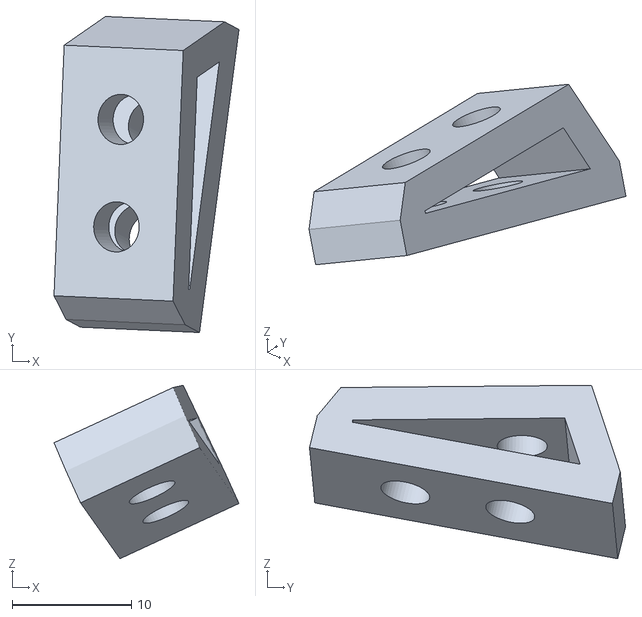
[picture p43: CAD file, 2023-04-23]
files/mcu/left-mcu base angle.stl
15.5 x 26.5 x 14.5

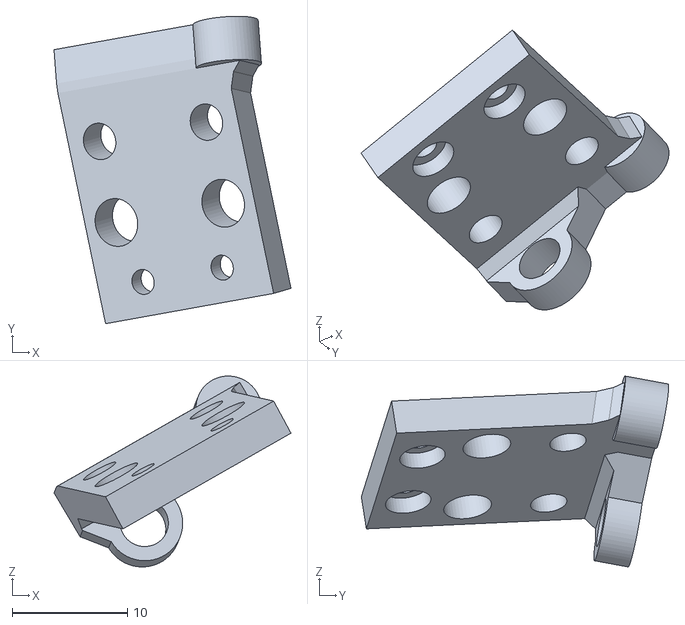
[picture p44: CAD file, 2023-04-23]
files/thumb/right-thumb AB plate.stl
20.6 x 26.7 x 16.6

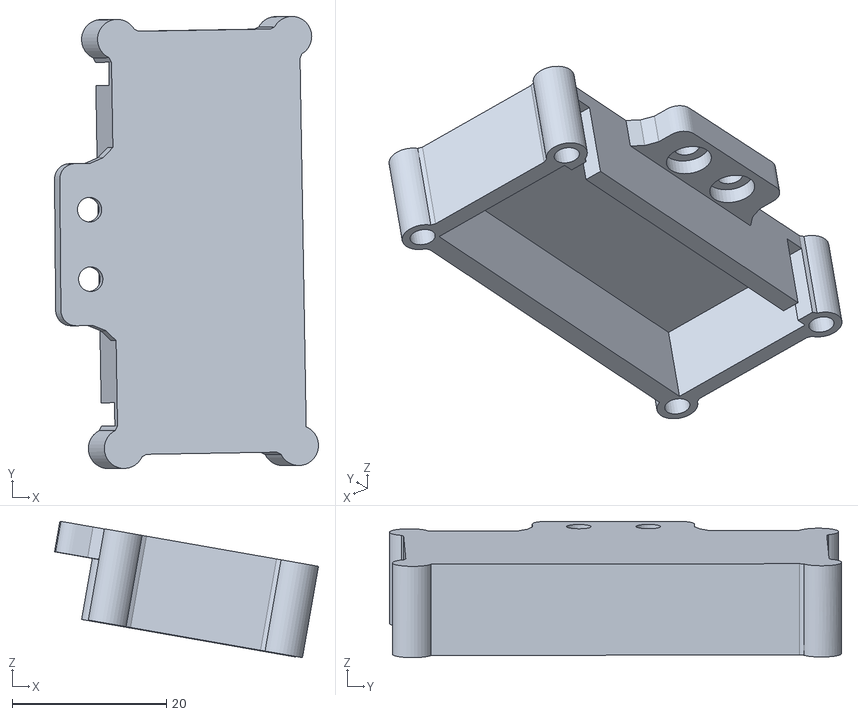
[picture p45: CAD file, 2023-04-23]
files/battery/right-box 102050.stl
34.2 x 58.6 x 17.6

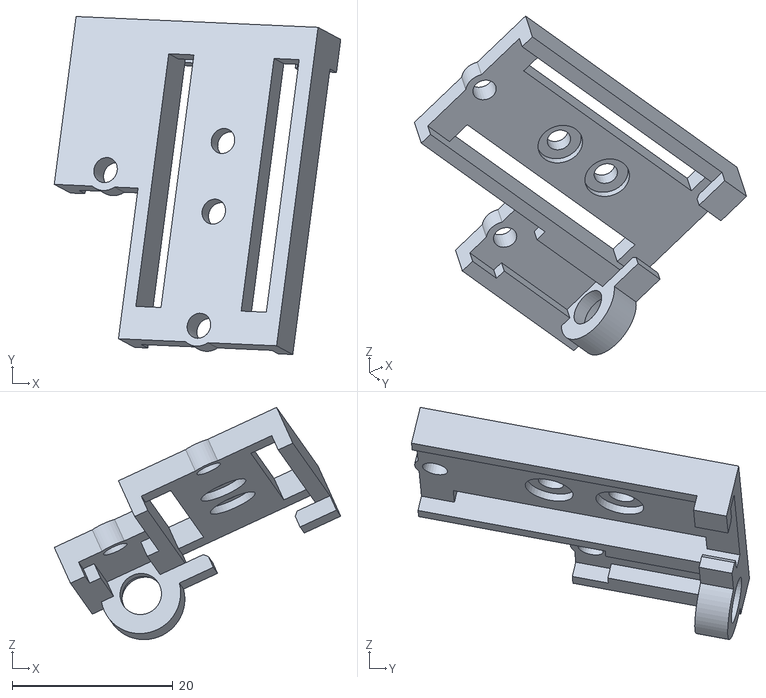
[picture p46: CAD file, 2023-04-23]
files/mcu/left-trrs mcu base.stl
35.6 x 42.0 x 28.9

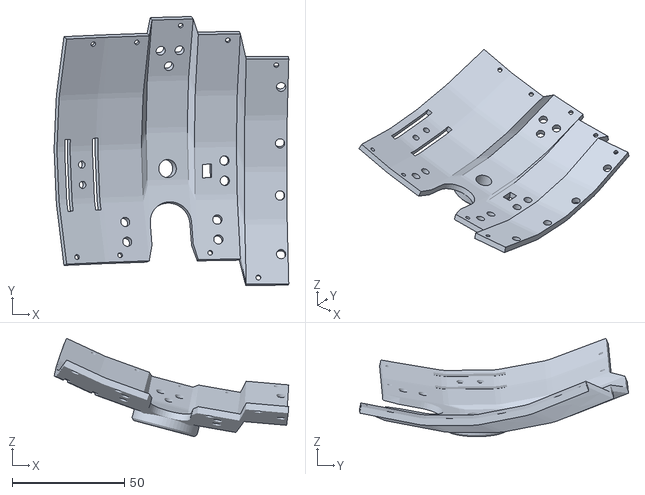
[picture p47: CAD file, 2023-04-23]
files/right-4x5 bottom case.stl
104.4 x 119.8 x 43.8

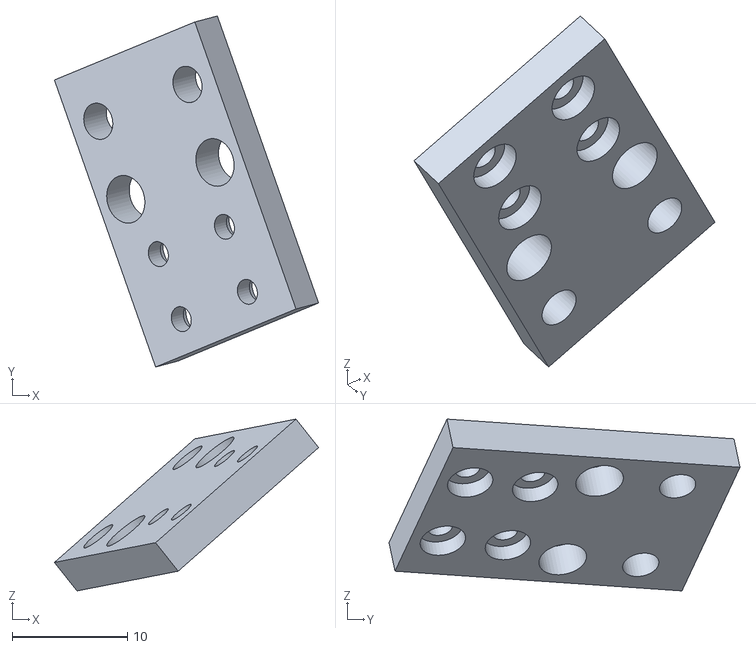
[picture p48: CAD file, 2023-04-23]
files/thumb/right-thumb BA plate.stl
22.9 x 30.5 x 14.9

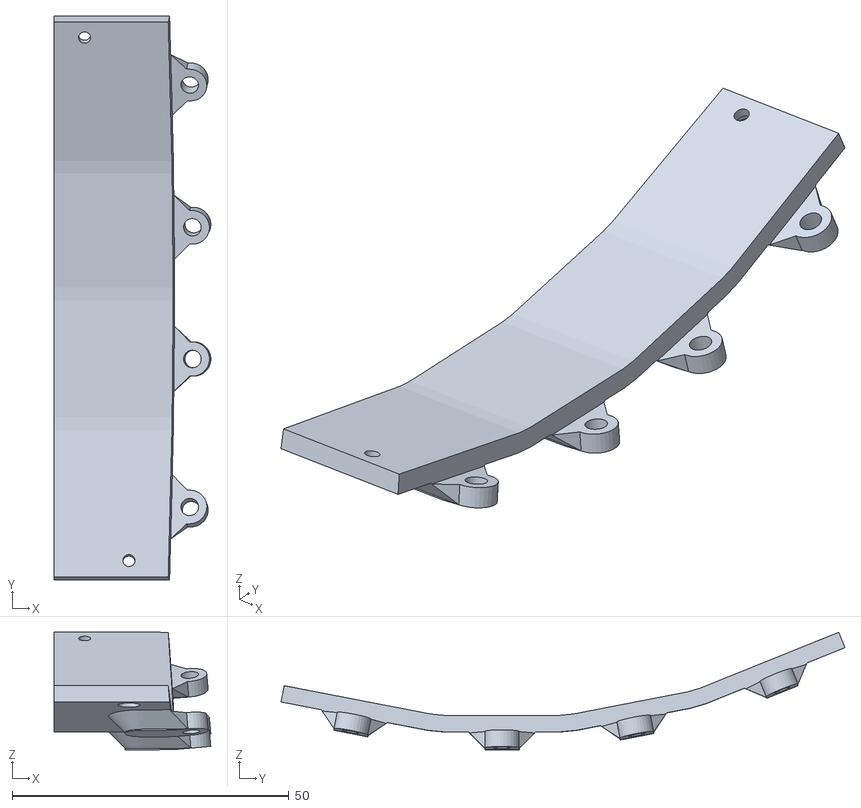
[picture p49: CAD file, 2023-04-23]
files/left-4x1 bottom expand case.stl
28.3 x 101.9 x 21.2

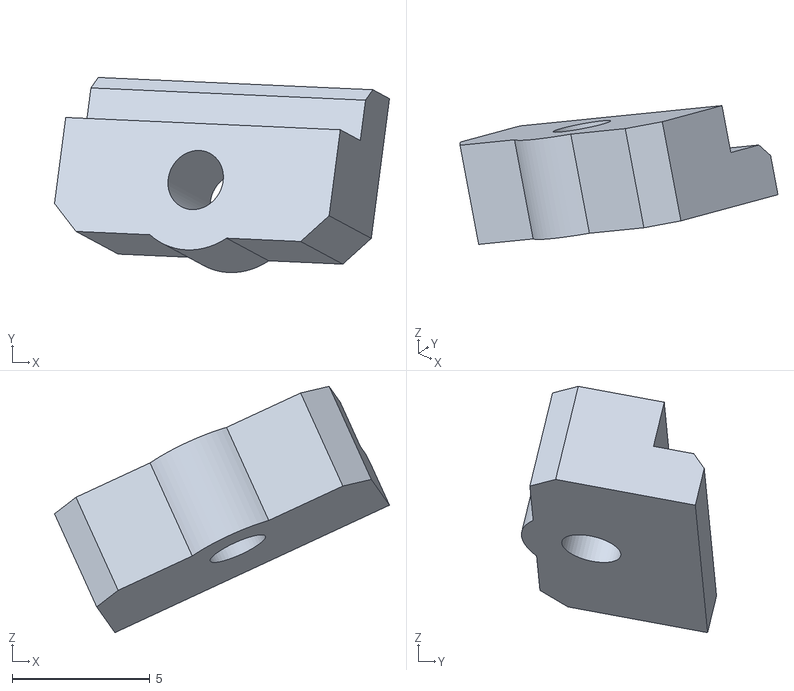
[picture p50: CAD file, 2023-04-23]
files/mcu/left-mcu stuck.stl
12.2 x 7.08 x 8.94

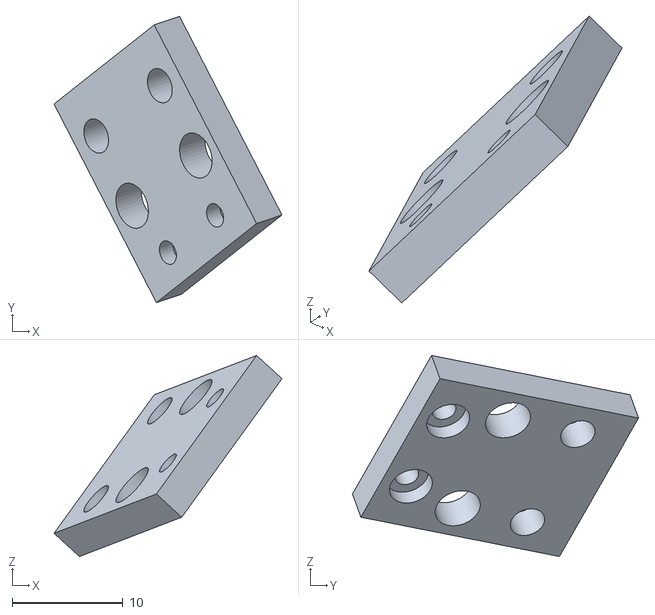
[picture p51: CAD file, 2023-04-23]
files/thumb/right-thumb BB plate.stl
20.6 x 25.8 x 18.2

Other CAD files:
files/left-4x5 upper main frame.stl
files/right-3x5 upper main frame.stl
files/right-lower main frame.stl
files/battery/left-box 102050.stl
files/3x1-column.stl
files/4x1-column.stl
files/battery/left-box 602050.stl
files/battery/left-box 802050.stl
files/battery/right-box 602050.stl
files/battery/right-box 802050.stl
files/battery/right-case cover.stl
files/left-3x1 bottom expand case.stl
files/left-3x5 bottom case.stl
files/left-4x5 bottom case.stl
files/left-front basepart.stl
files/mcu/left-mcu base.stl
files/mcu/left-trrs stuck.stl
files/mcu/right-mcu base angle.stl
files/mcu/right-mcu base.stl
files/mcu/right-mcu stuck.stl
files/mcu/right-trrs mcu base.stl
files/mcu/right-trrs stuck.stl
files/right-3x1 bottom expand case.stl
files/right-3x5 bottom case.stl
files/right-4x1 bottom expand case.stl
files/right-front basepart.stl
files/thumb/left-thumb AA plate.stl
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

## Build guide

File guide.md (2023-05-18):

# 組裝說明（Building Guide）
## 安全注意事項

> **Warning**
>
> 1. 使用電烙鐵時注意環境通風。
> 
> 2. 部分零件在壓製熱壓螺母時需要用手做固定及公差微調，注意不要燙傷。
> 
> 3. 3D列印的部件相當脆弱，務必不要過度用力彎折、摔、掉落、螺絲硬鎖等行為。

## 工具準備

- 溫控電烙鐵及相關工具配件。
- 烙鐵工作臺（帶夾子固定、吸磁固定為佳）
- 剝線鉗。
- 美工刀。
- 切割墊。
- 精密螺絲起子。
- 寬頭鑷子。
- 小剪刀
- 熱風槍。
- 超黏無痕雙面膠。
- 絕緣膠帶。
- 1u鍵帽若干。

## 材料準備

> **Note**
> 
> 1. 熱壓螺母及螺絲的使用量相當多，推薦直接買一包備著用。
>
> 2. 能夠在同一個賣場買就在同一個賣場買，比較省錢。
>
> 3. 推薦使用單格電路板組裝，邏輯比較好懂，也比較好拉矩陣佈線。
>
> 4. 電線不一定要按照表格上標示的顏色購買，2種不同的顏色即可，方便走線佈線及防呆。

| 材料名稱 | 左右手合計最大用量 | 相關連結 |
| --- | ---- | --- |
| M2x3x3.2mm 熱壓螺母 | 76 | [Link](https://detail.tmall.com/item.htm?_u=n3lhas116742&id=673922235027&spm=a1z09.2.0.0.18132e8d8onSZm) |
| M3x3x4.2mm 熱壓螺母 | 62 | [Link](https://detail.tmall.com/item.htm?_u=n3lhas116742&id=673922235027&spm=a1z09.2.0.0.18132e8d8onSZm) |
| M2x5mm 薄頭螺絲 | 50 | [Link](https://detail.tmall.com/item.htm?_u=n3lhas111f9d&id=595144522232&spm=a1z09.2.0.0.18132e8d8onSZm) |
| M2x8mm 薄頭螺絲 | 22 | [Link](https://detail.tmall.com/item.htm?_u=n3lhas111f9d&id=595144522232&spm=a1z09.2.0.0.18132e8d8onSZm) |
| M3x6mm 薄頭螺絲 | 54 | [Link](https://detail.tmall.com/item.htm?_u=n3lhas111f9d&id=595144522232&spm=a1z09.2.0.0.18132e8d8onSZm) |
| M3x8mm 薄頭螺絲 | 2 | [Link](https://detail.tmall.com/item.htm?_u=n3lhas111f9d&id=595144522232&spm=a1z09.2.0.0.18132e8d8onSZm) |
| M3x6mm 扁頭螺絲 | 8 | [Link](https://detail.tmall.com/item.htm?_u=n3lhas11735e&id=624733978863&spm=a1z09.2.0.0.18132e8d8onSZm) |
| 1/4" 高6.35mm 熱壓螺母 | 4 | [Link](https://item.taobao.com/item.htm?spm=a1z0d.6639537/tb.1997196601.82.3d385886uNMAFA&id=662099841891) |
| Pro Micro 5V16M | 2 | [Link](https://item.taobao.com/item.htm?spm=a1z09.2.0.0.18132e8d8onSZm&id=682095206177&_u=n3lhas111158) |
| TRRS座 | 2 | [Link](https://detail.tmall.com/item.htm?_u=n3lhas11d3b2&id=609114863623&spm=a1z09.2.0.0.18132e8d8onSZm) |
| 28AWG 白色矽膠線 | N/A | [Link](https://item.taobao.com/item.htm?spm=a1z09.2.0.0.18132e8d8onSZm&id=45709657945&_u=n3lhas114d82) |
| 28AWG 紅色矽膠線 | N/A | [Link](https://item.taobao.com/item.htm?spm=a1z09.2.0.0.18132e8d8onSZm&id=45709657945&_u=n3lhas114d82) |
| 2.54mm 圓排針公 | N/A | [Link](https://item.taobao.com/item.htm?spm=a1z09.2.0.0.18132e8d8onSZm&id=627707215622&_u=n3lhas11f450) |
| 2.54mm 圓排針母 | N/A | [Link](https://item.taobao.com/item.htm?spm=a1z09.2.0.0.18132e8d8onSZm&id=627818679656&_u=n3lhas11659a) |
| 外徑1mm 熱縮套管 | N/A | [Link](https://shopee.tw/(%E5%8F%B0%E7%81%A3%E5%A4%A7%E5%BB%A0%E8%A3%BD)%E9%80%8F%E6%98%8E%E7%86%B1%E7%B8%AE%E5%A5%97%E7%AE%A1%E8%B3%A3%E5%A0%B4-%E7%86%B1%E7%B8%AE%E5%A5%97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) |
| 單格電路板 | 56 | [Link](https://www.pragmatic.com.tw/shop/single-switch-pcb-101#attr=) |
| 1N1418 貼片式T4 開關二級管 | 56 | [Link](https://detail.tmall.com/item.htm?_u=n3lhas111e26&id=614392649945&spm=a1z09.2.0.0.18132e8d8onSZm) |

## 列印注意事項

> **Note**
> 
> 1. 根據需求先決定自己需要3x5、3x6或4x5、4x6等鍵盤主配列，如果不清楚的話，請先決定自己的鍵盤要幾排（Row）按鍵。
> 
> 2. 不知道拇指要幾顆按鍵，請全部列印出來。
> 
> 3. 這把鍵盤叫做探索者，就如其名，它需要你慢慢探索鍵盤按鍵中的奧祕。

## 配列部件表

> **Note**
> 
> 部分組件為對稱設計，但檔案數量龐大，還是將組件建立成左右區分，方便大家列印時參考用。

| 部件名稱 | 左右區分 | 選項A | 選項B | 備註 |
| --- | --- | ----- | ----- | ---- |
| 直列定位板（column） | - | 3x1 | 4x1 | 5列鍵盤需列印10組、6列12組 |
| 底殼（bottom case） | Yes | 3x5 | 4x5 | - |
| 底殼拓展（bottom expand case） | Yes | 3x1 | 4x1 | - |
| 上框架（upper main frame） | Yes | 3x5 | 4x5 | 3x5、4x5不共用 |
| 共用下框（lower main frame） | Yes | - | - | 3x5、4x5通用 |
| 拓展框架（x1-main frame） | - | - | - | 一組左右拓展需列印4組 |
| 前方雲台插件（front basepart） | Yes | - | - | 左右邊可通用 |
| 拇指區基座（thumb area basepart） | Yes | - | - | - |
| 拇指定位板（x1-thumb plate） | - | - | - | 依據拇指按鍵數量列印 |
| 拇指底板AX（thumb AX plate） | Yes | AA（長板） | AB（短板） | 可連結基座 |
| 拇指底板BX（thumb BX plate） | Yes | BA（長板） | BB（短板） | 純拓展，左右通用 |
| 連接器（linker） | - | - | - | 左右通用，2組按鍵需用1組連接器 |
| TRRS主控底座（trrs mcu base） | Yes | MCU卡扣（mcu stuck） | TRRS卡扣（trrs stuck） | - |
| 無線主控底座（mcu base） | Yes | MCU卡扣（mcu stuck） | - | 左右通用 |
| 斜角插件（mcu base angle） | Yes | - | - | 左右通用，必要組件 |
| 電池倉上蓋（case cover） | Yes | - | - | 左右通用，厚度通用 |
| 電池盒（box） | Yes | - | - | 左右通用，2050（20x50mm）規格，厚度6mm、8mm、10mm可選 |

## 組裝步驟

> **Note**
> 
> 1. 3x5、3x6及4x5、4x6鍵盤配列安裝大同小異，這裡會以配列最大的4x6+4鍵盤演示為主。
> 
> 2. 簡單的一個邏輯，跟外殼連接相關使用M3，跟定位板相關使用M2，請依據這個邏輯進行安裝。

> **Warning**
> 
> 第一步先安裝熱壓螺母，電烙鐵使用定溫200度即可，溫度太高PLA外殼會融化。

### （一）熱壓螺母

- 探索者1號會使用到M2x3x3.2mm、M3x3x4.2mm及英制1/4"高6.35mm三種規格之熱壓螺母，每個部件都會按照下圖的顏色做標示，方便安裝。
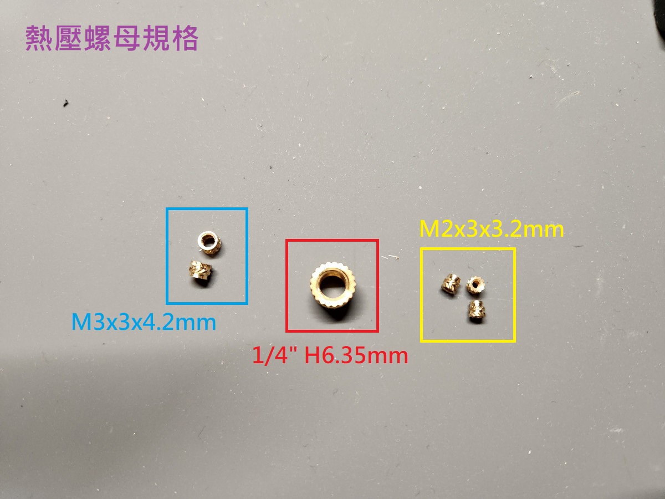
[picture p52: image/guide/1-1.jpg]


- Column-3x1、4x1：
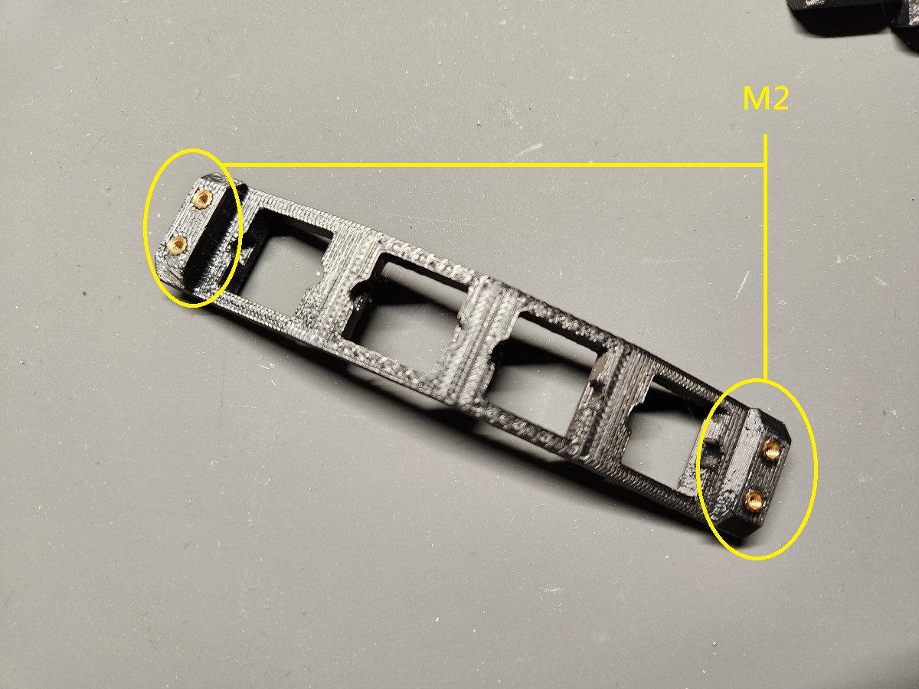
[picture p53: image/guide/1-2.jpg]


- x1-thumb plate：
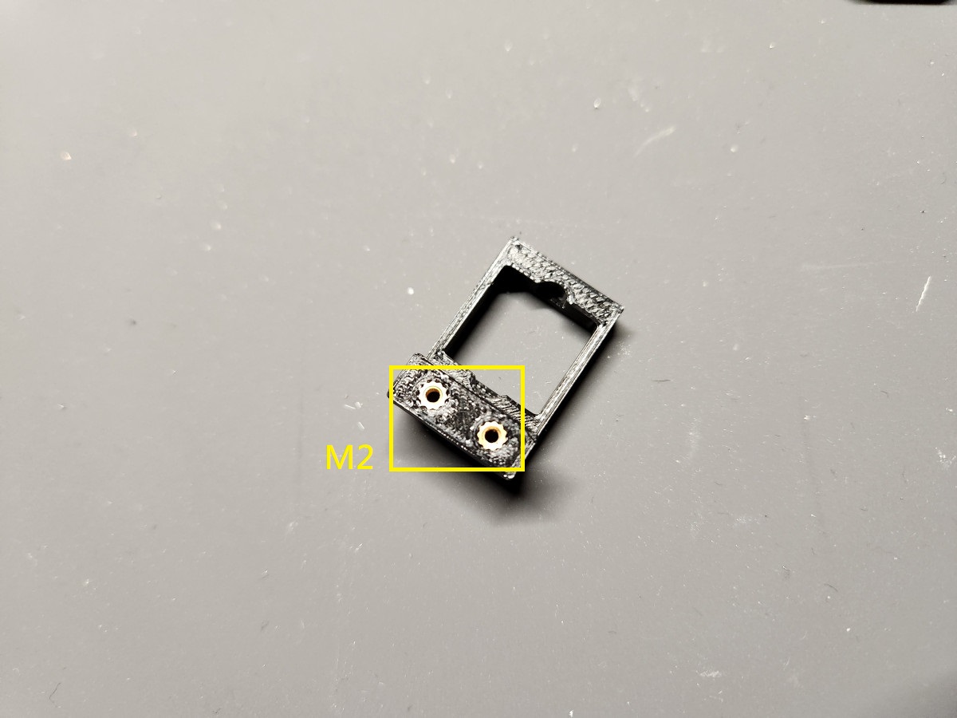
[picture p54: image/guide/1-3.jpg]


- thumb AA plate、thumb AB plate：
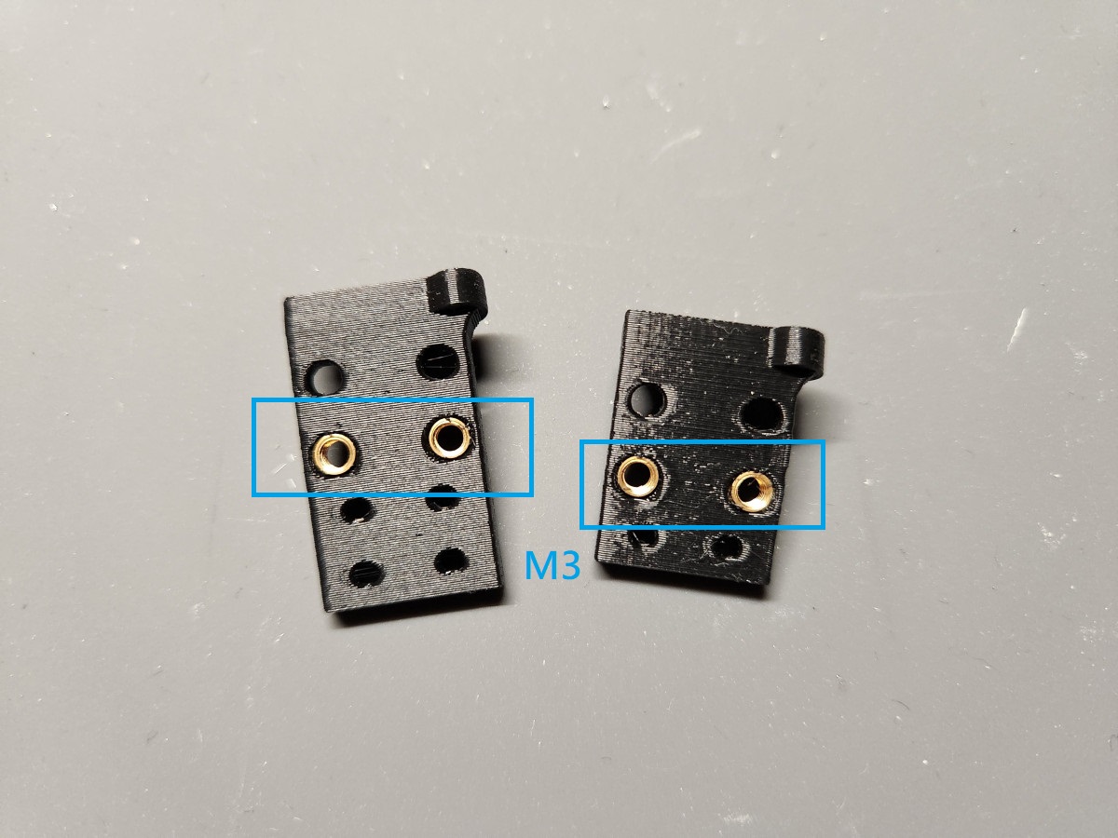
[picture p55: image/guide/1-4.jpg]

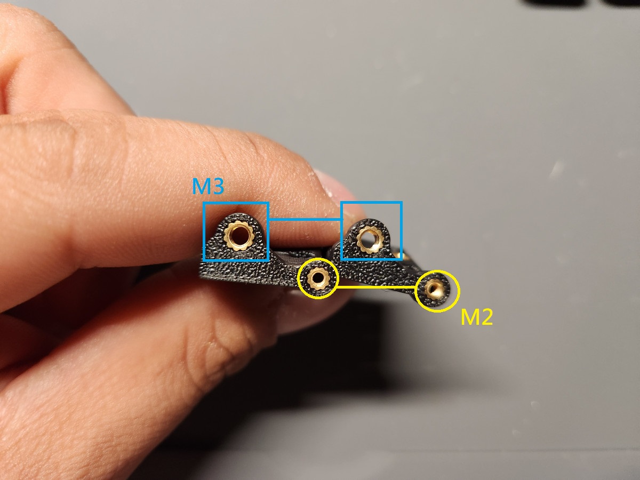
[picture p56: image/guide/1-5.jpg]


- thumb BA plate、thumb BB plate：
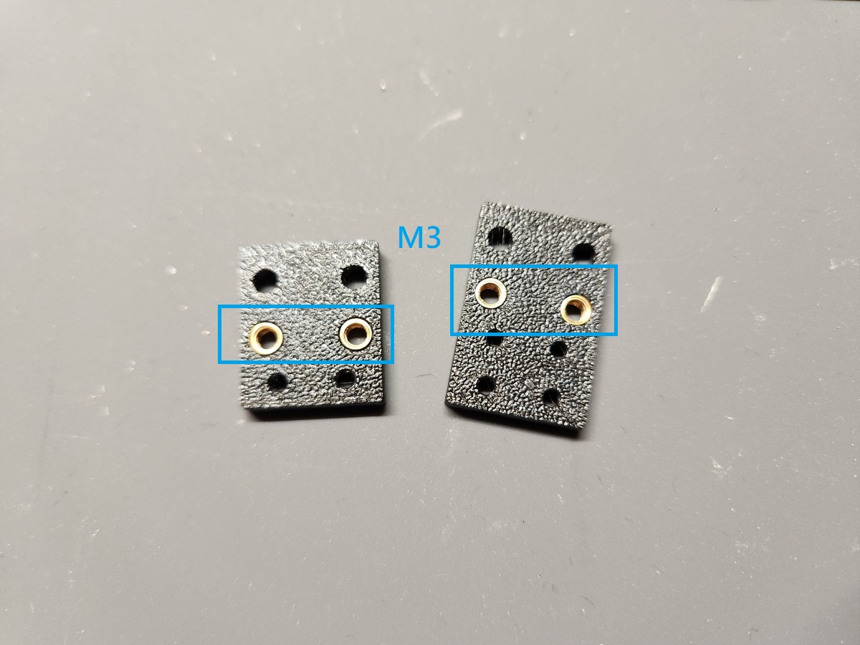
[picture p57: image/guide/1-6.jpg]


- linker：
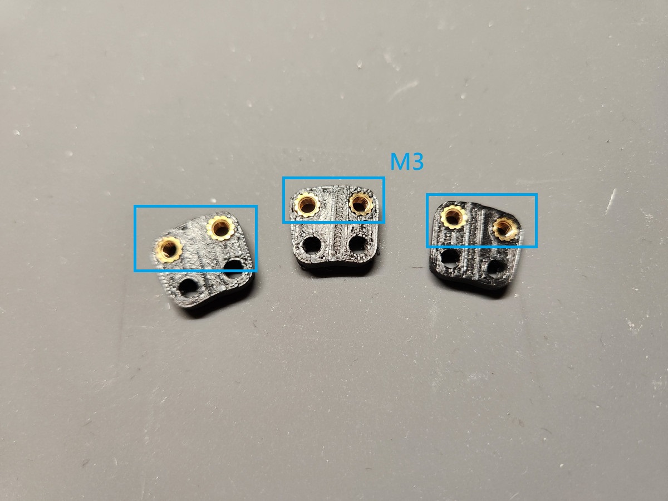
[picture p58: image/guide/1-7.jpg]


- 4x6 bottom case，3x6會少用1個M3螺母，安裝方式大同小異：
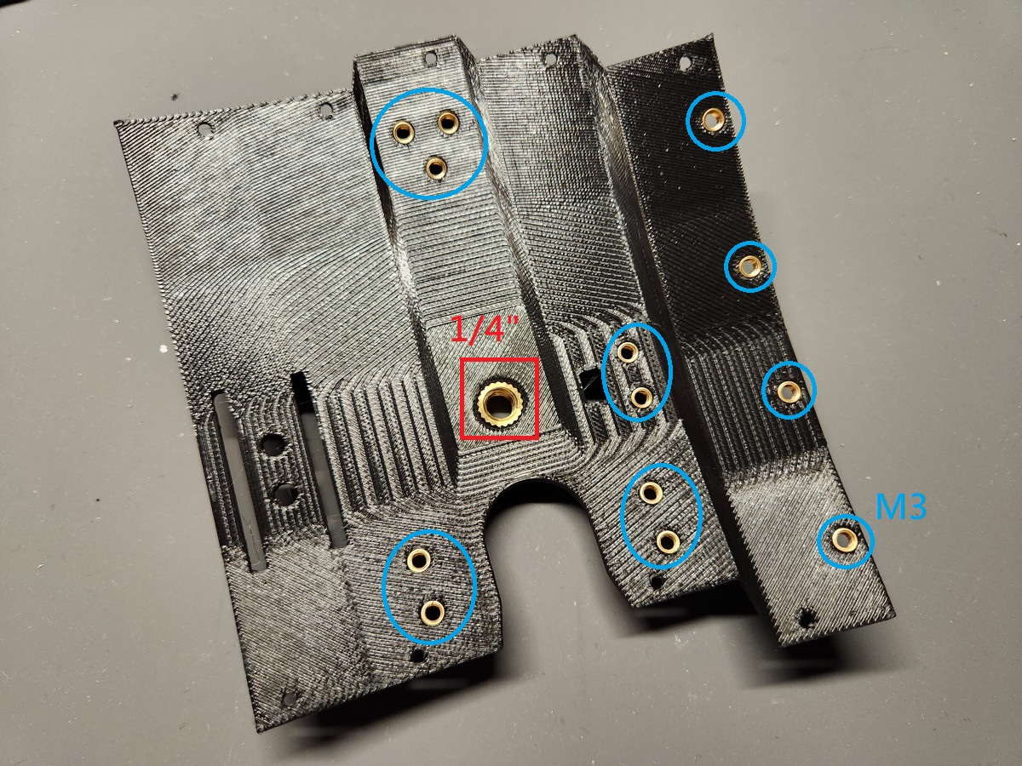
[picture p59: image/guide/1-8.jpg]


- box：
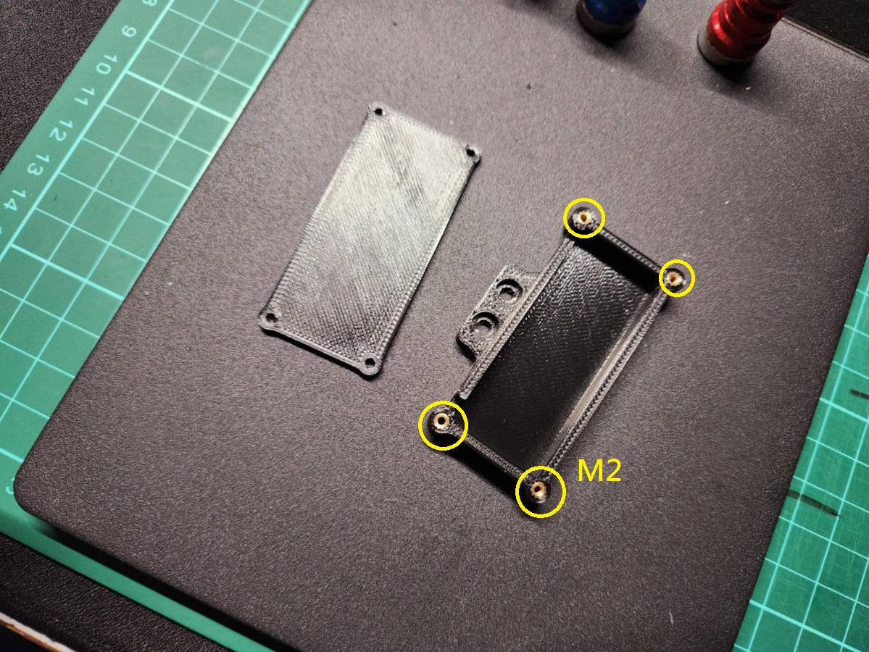
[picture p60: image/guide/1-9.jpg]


- trrs mcu base、mcu base，安裝方式一樣：
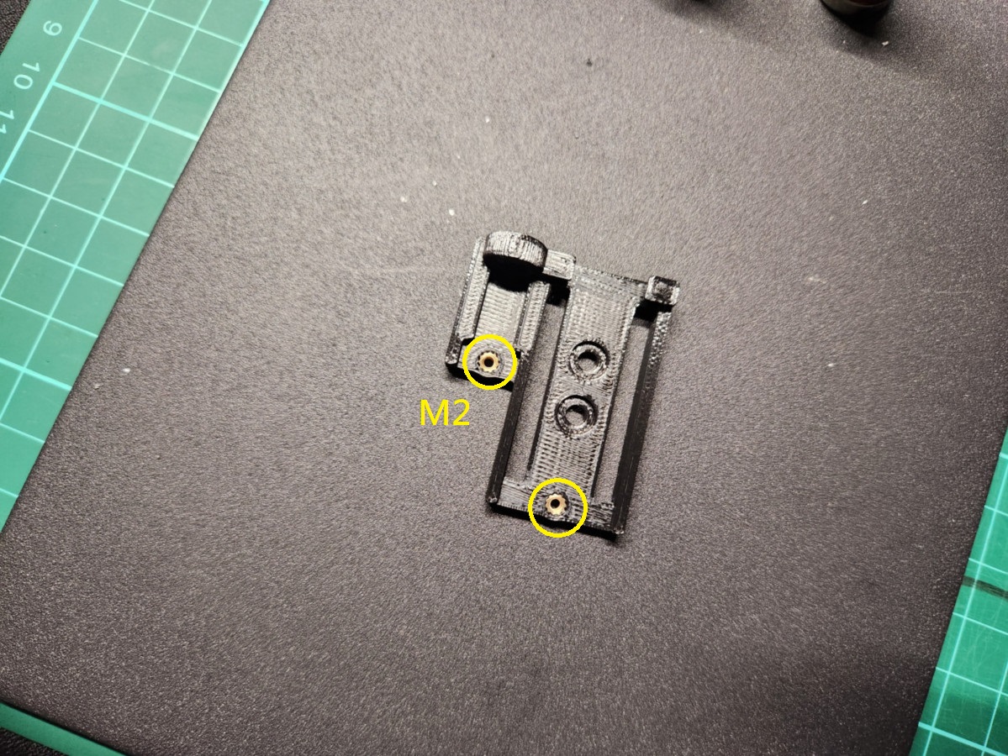
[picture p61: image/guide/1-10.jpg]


- mcu base angle：
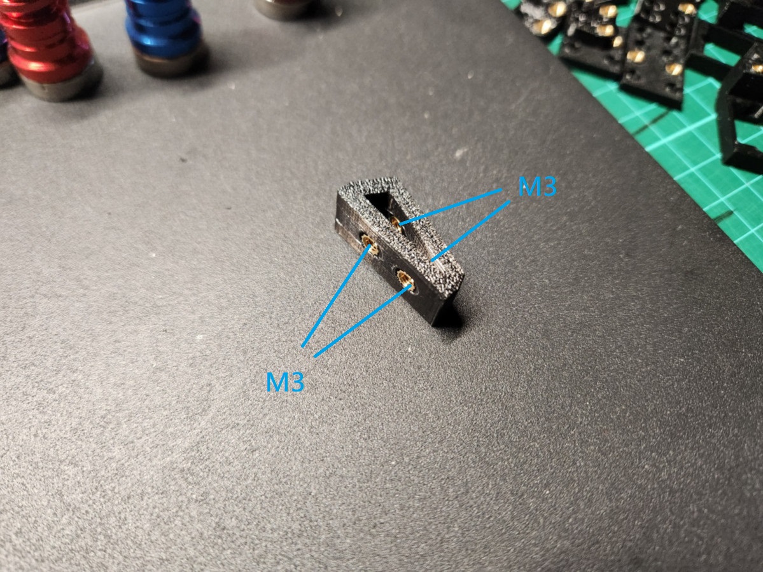
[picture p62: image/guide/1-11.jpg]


- front basepart：
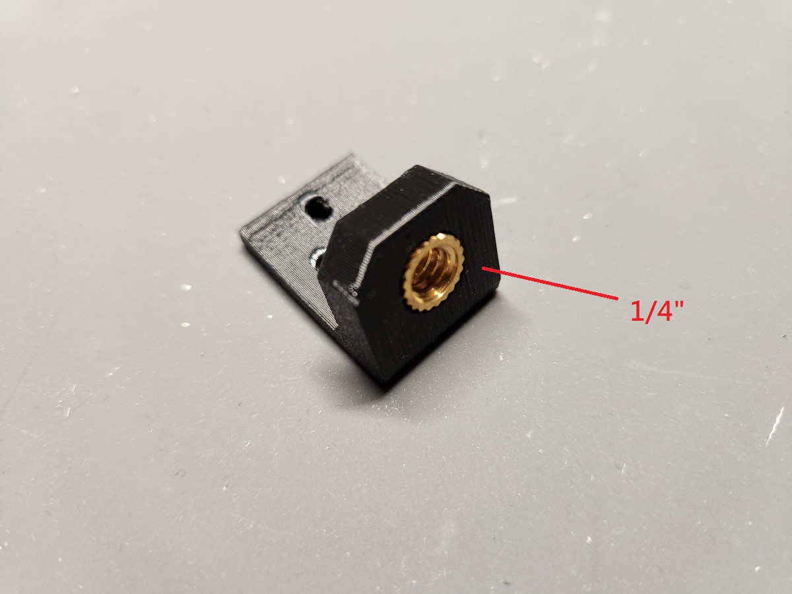
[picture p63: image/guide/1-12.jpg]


### （二）外殼安裝順序

> **Note**
> 
> 探索者1號由於是模組化設計，大體設計出來的部件數量相當龐大外，如果不瞭解如何安裝外殼，後續的安裝步驟會很困難，務必將各個部件的安裝方式及步驟記下。

#### A、外殼部分

- 首先將主控座的部分用螺絲固定上：
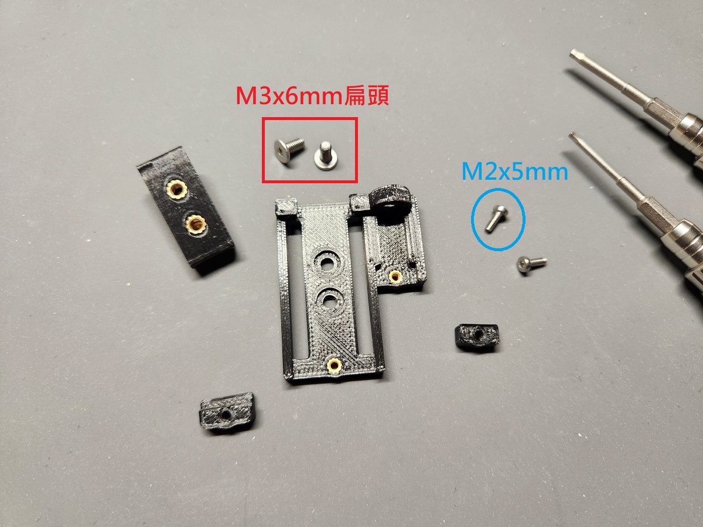
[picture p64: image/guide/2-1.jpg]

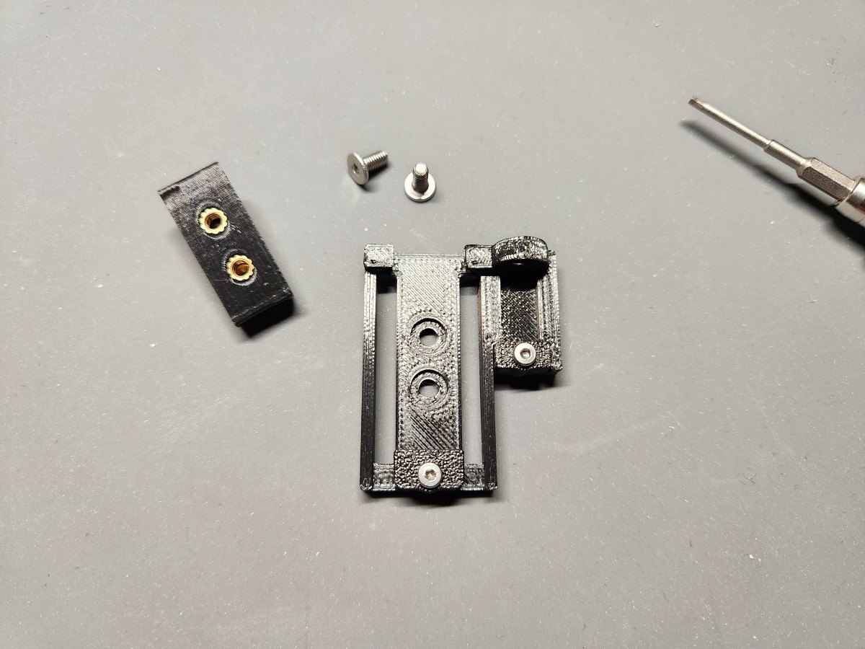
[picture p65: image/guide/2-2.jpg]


- 再將斜角插件固定在主控座上：
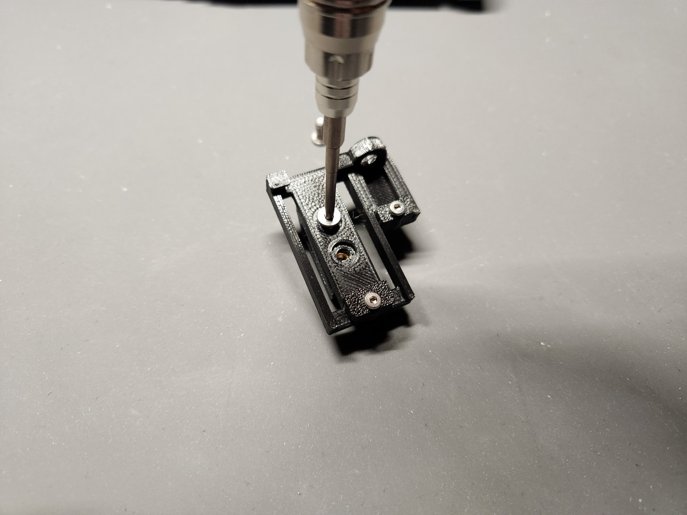
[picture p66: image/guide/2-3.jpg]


- 主控座的部分會在製作排線的時候再繼續做介紹，先知道要如何安裝卡扣就好。
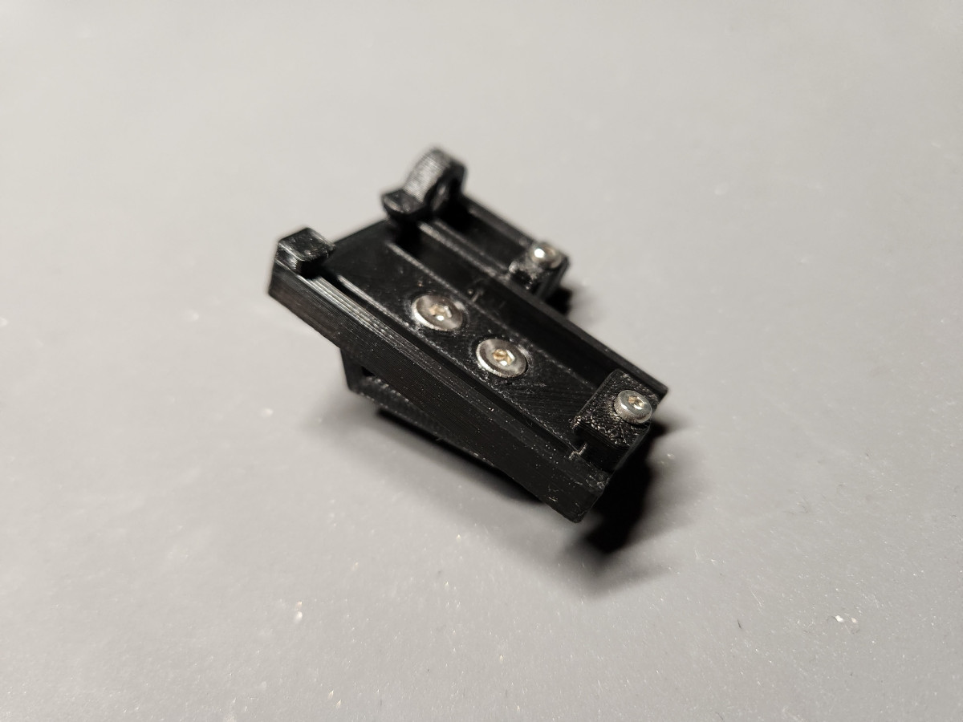
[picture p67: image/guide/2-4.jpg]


- 上框及下框的部分具有防呆機制，上框中指區會有2個孔、下框只會有1個孔，這點務必留意。
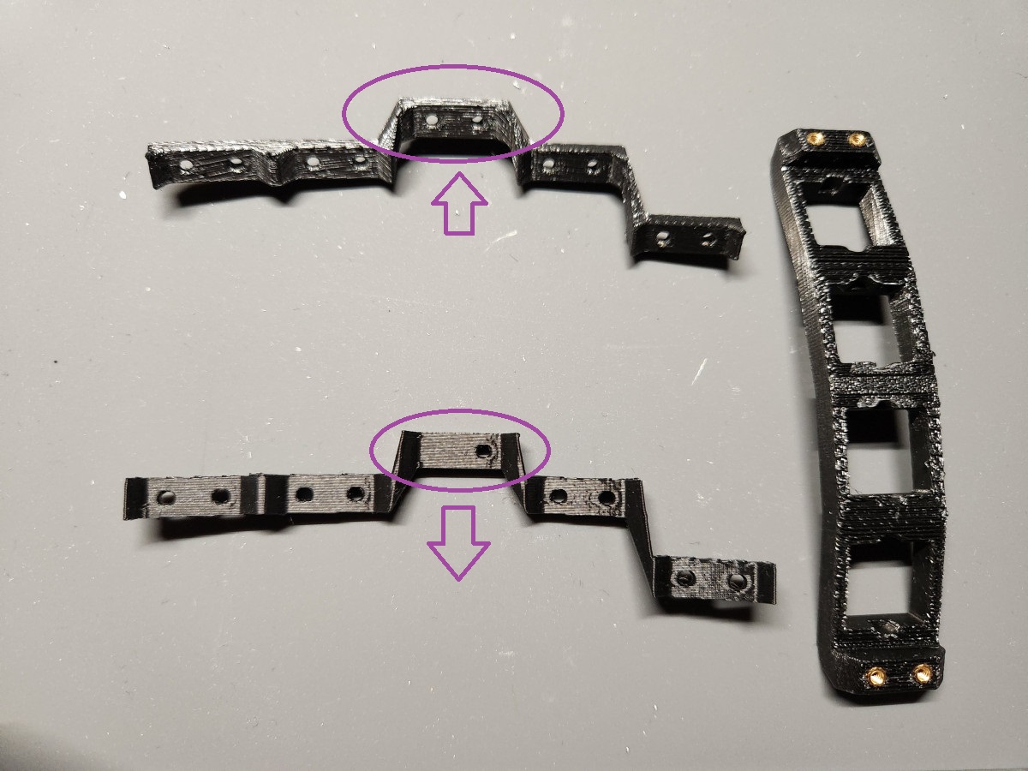
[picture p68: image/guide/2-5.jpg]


- 首先用M2x5的螺絲將框架及Column都固定上去，個人建議從最外側往內安裝會比較好固定。
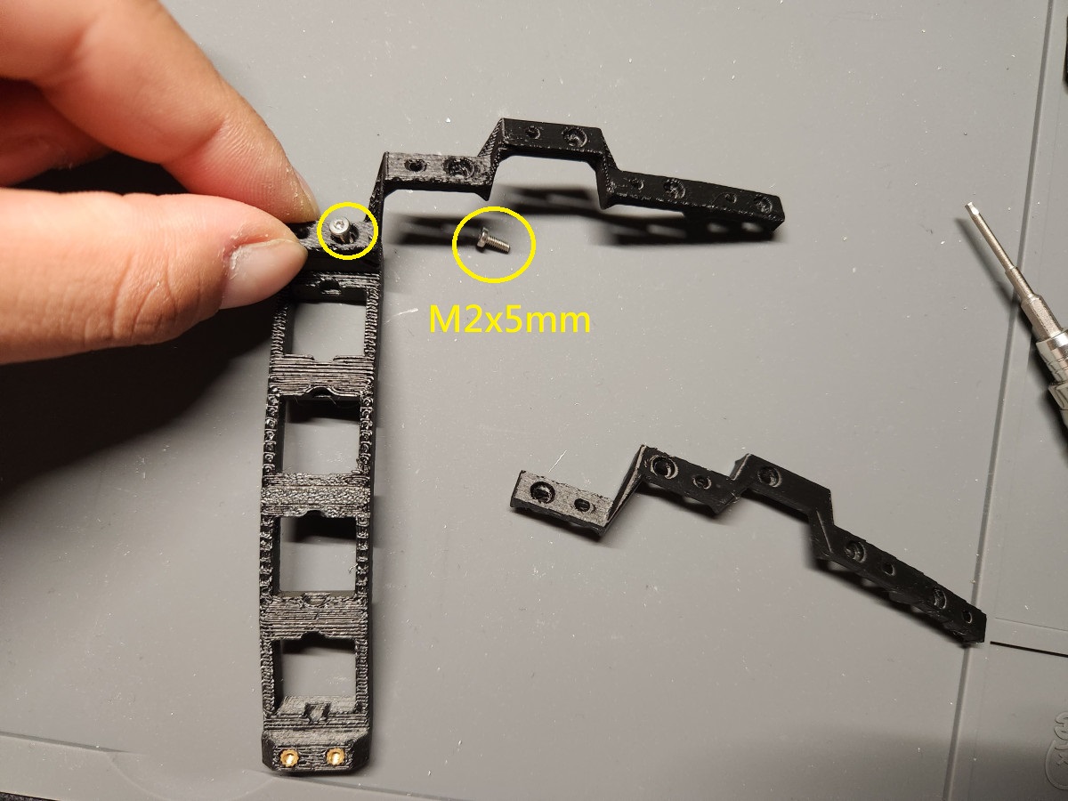
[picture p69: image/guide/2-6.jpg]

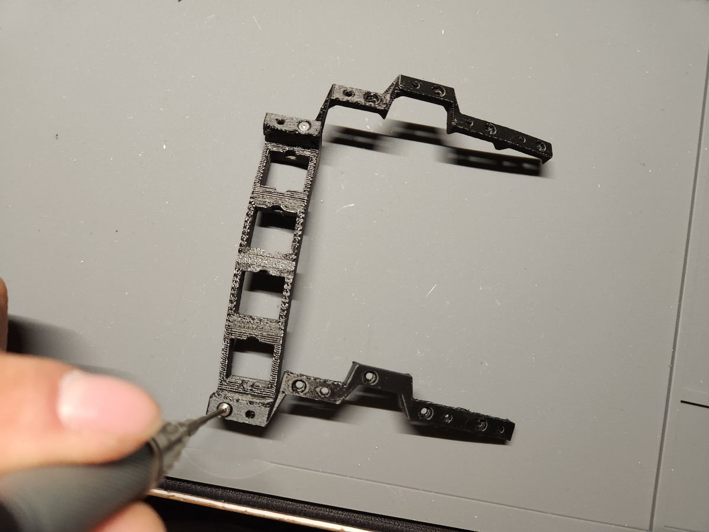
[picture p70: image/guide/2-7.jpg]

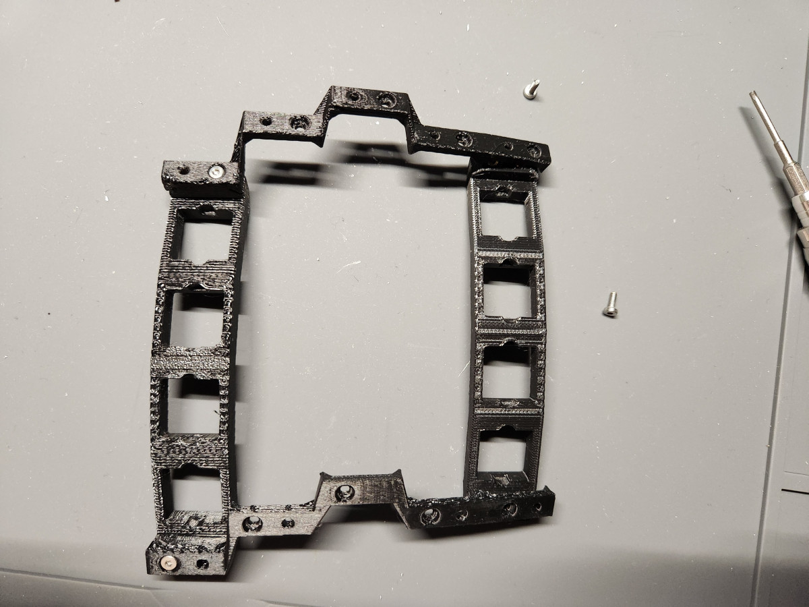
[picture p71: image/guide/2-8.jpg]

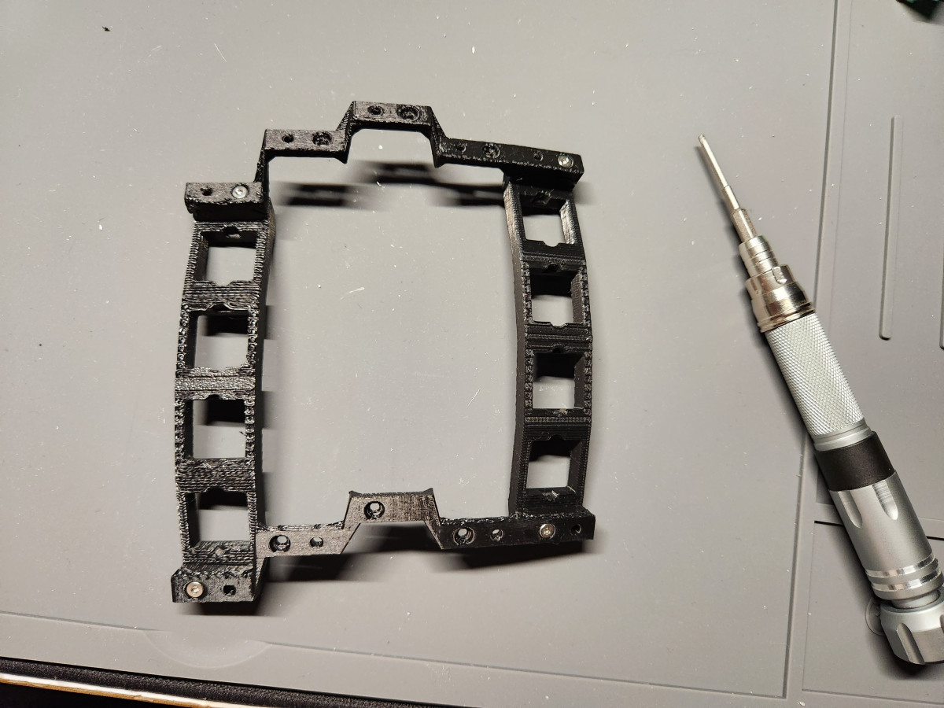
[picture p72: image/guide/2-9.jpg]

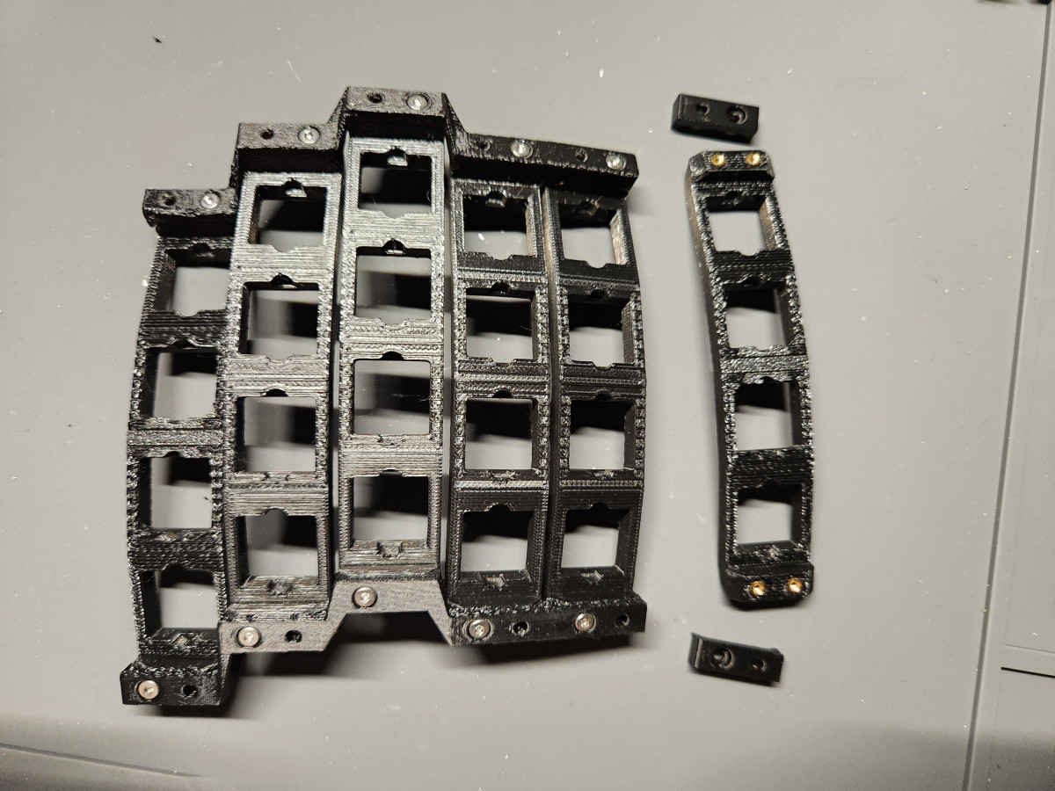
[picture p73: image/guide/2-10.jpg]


- 如果要安裝拓展的話，務必留意x1-main frame的螺絲安裝方向：
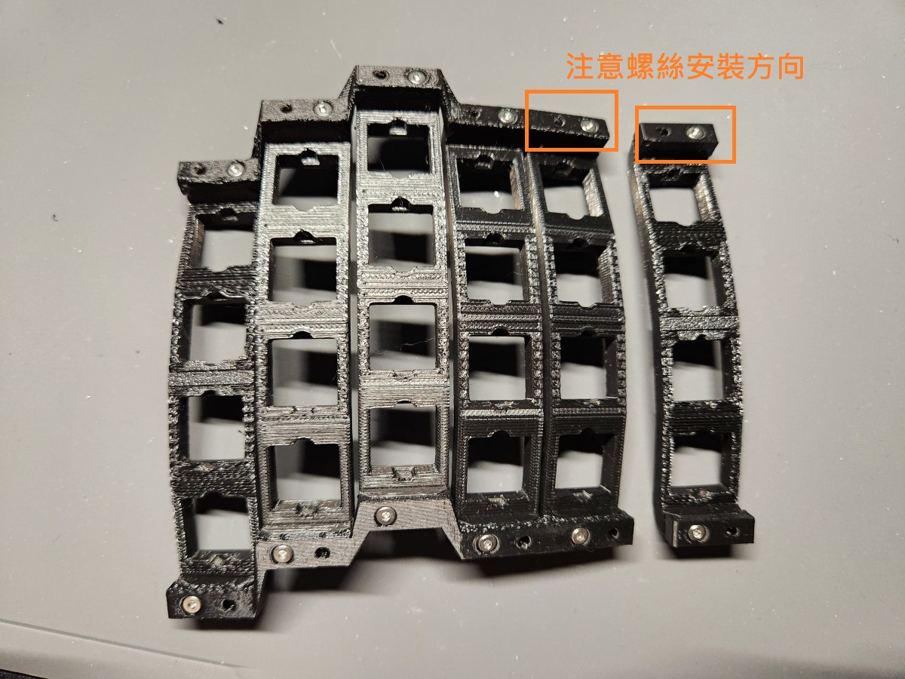
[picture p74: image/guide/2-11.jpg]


#### B、拇指區

- 拇指區基座部分由M3x8mm螺絲當作軸心、M2x5螺絲做角度固定，只有thumb BA plate、thumb BB plate可以連結基座，這裡再強調一次：
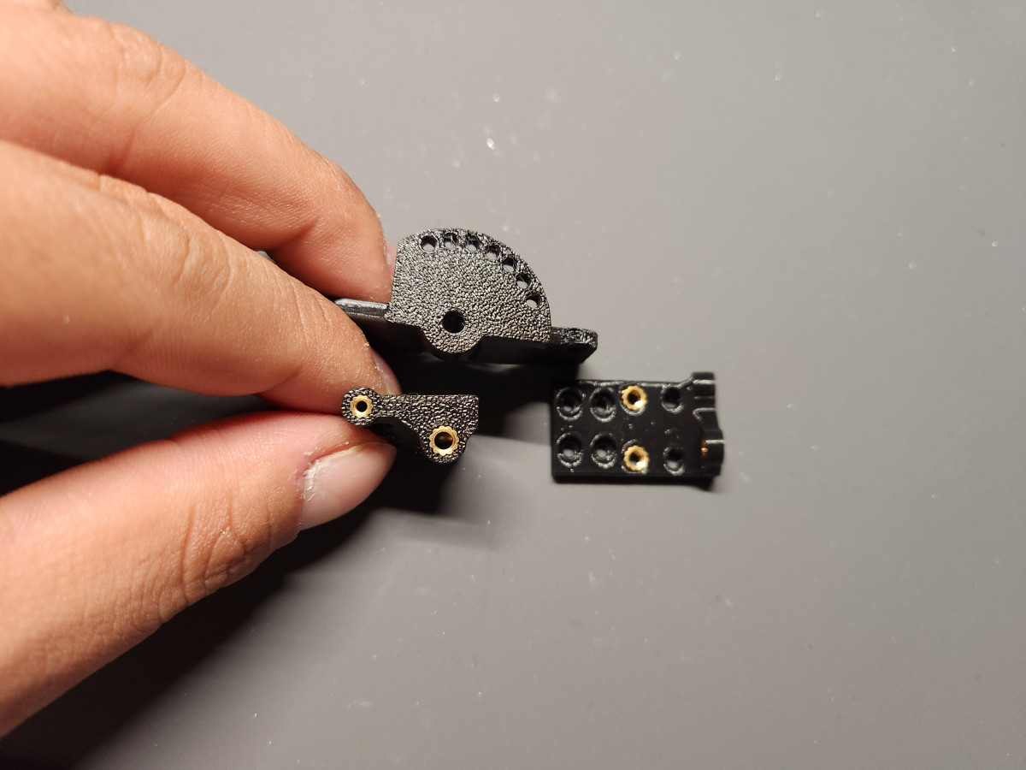
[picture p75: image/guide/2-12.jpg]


- 基座部分可以調整的角度為0～90度合計7個檔位，其中75度及90度檔需要使用M2x5mm規格之扁頭螺絲，基本不建議安裝。
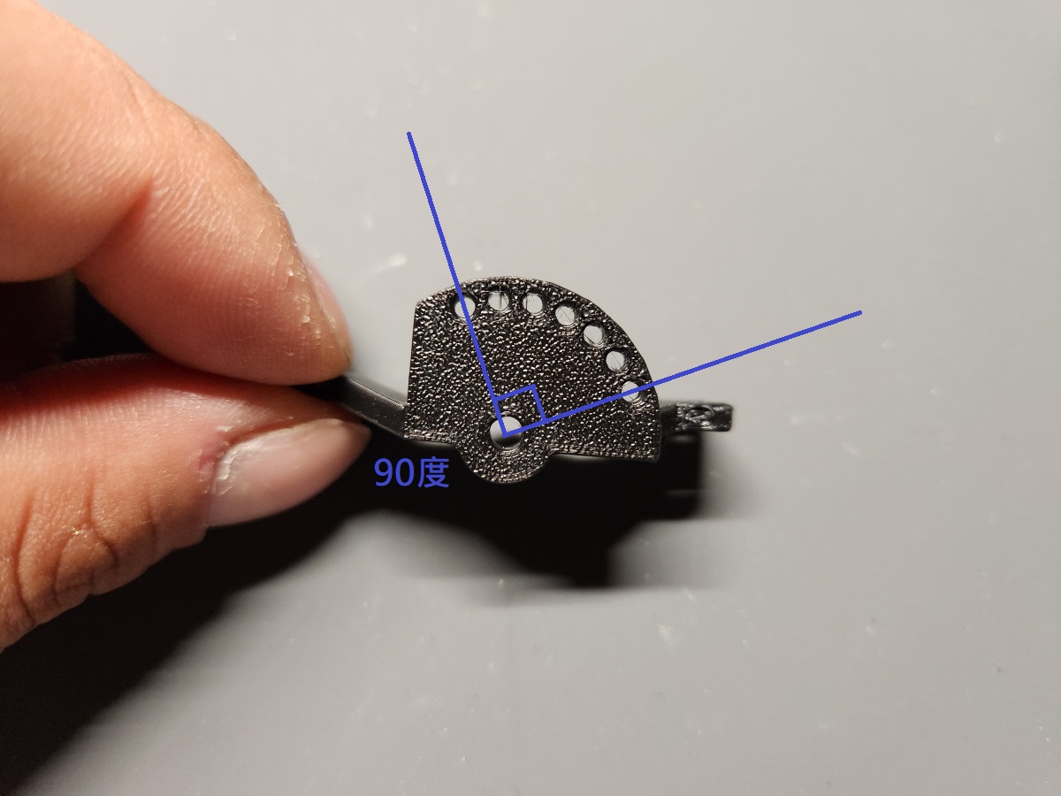
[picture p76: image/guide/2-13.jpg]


- 拇指按鍵底板的部分特別留意安裝角度：
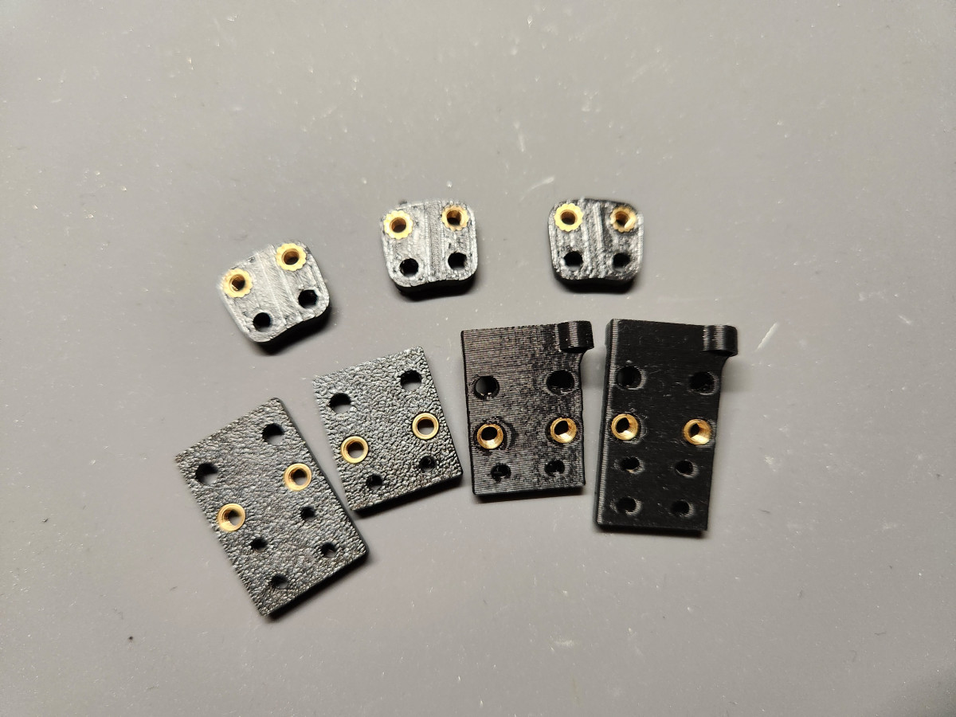
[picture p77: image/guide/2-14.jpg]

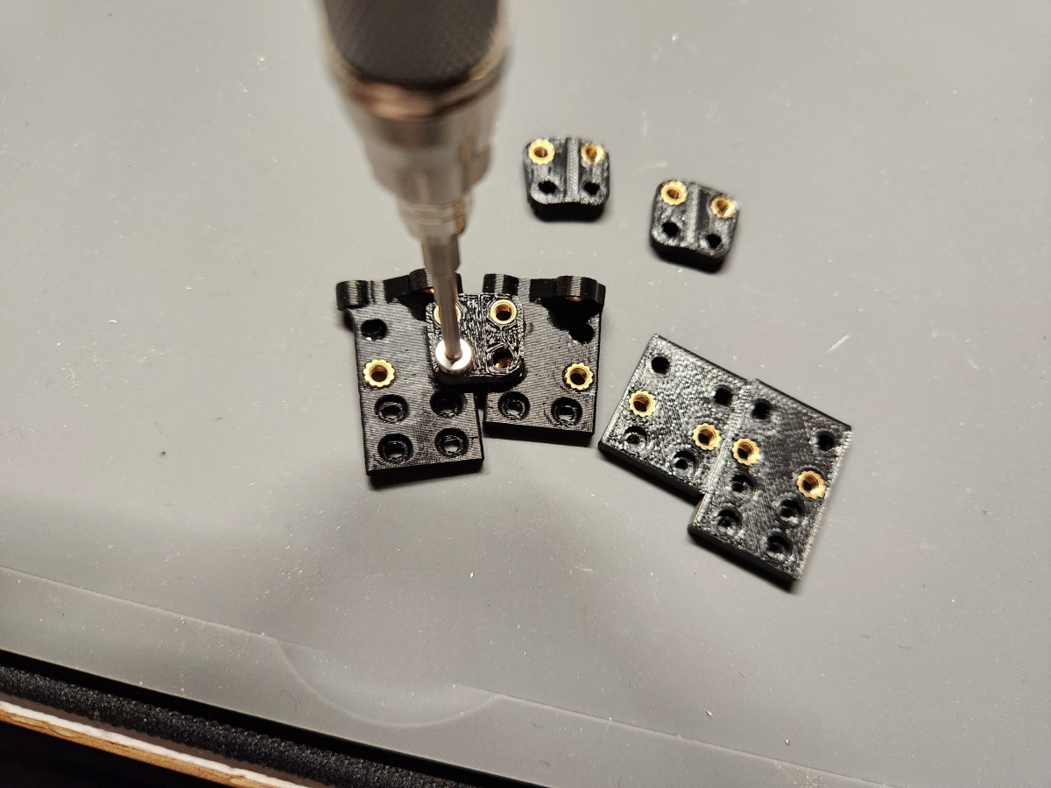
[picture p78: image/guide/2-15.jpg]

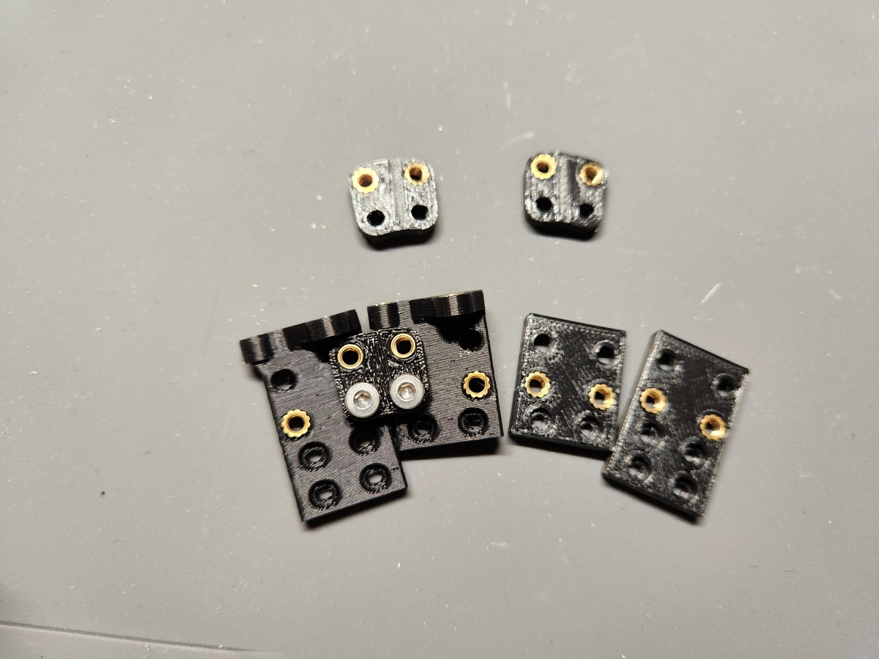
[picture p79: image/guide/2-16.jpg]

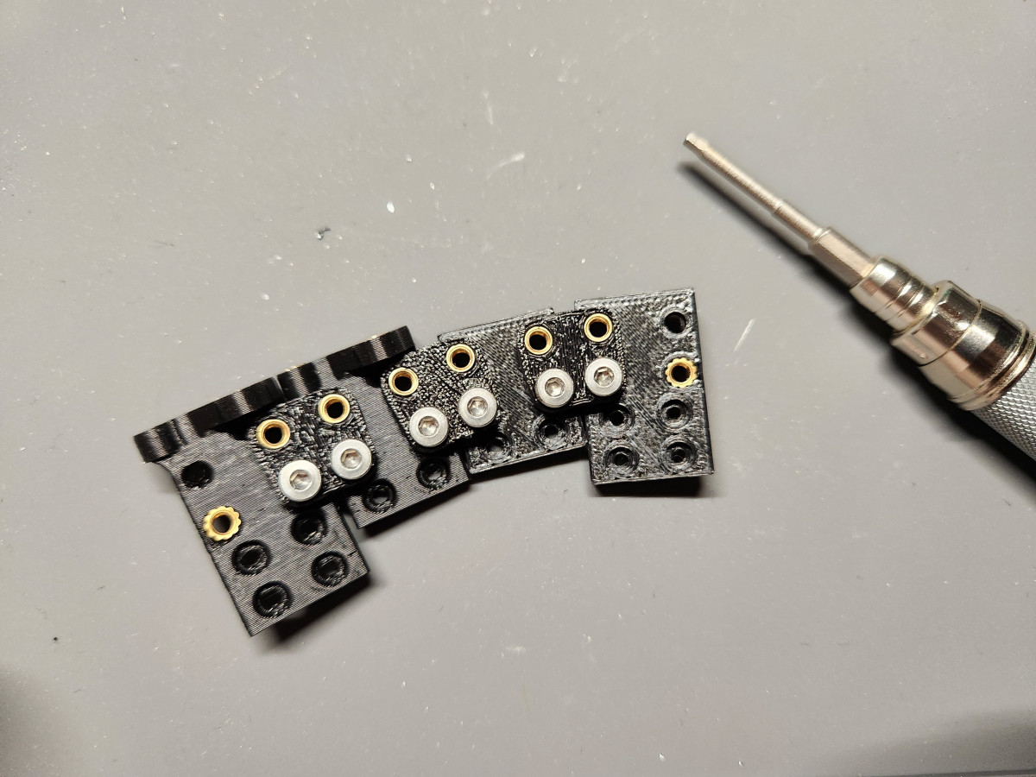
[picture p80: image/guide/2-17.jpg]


- 接著再安裝背面：
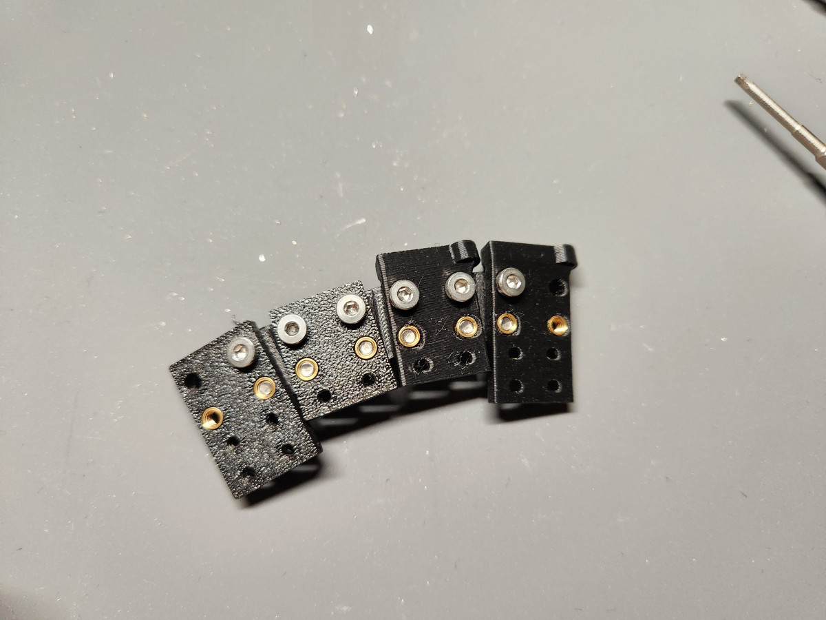
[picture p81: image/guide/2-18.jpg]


- 將拇指按鍵、基座組合在一起，選定好喜歡的角度後進行固定：
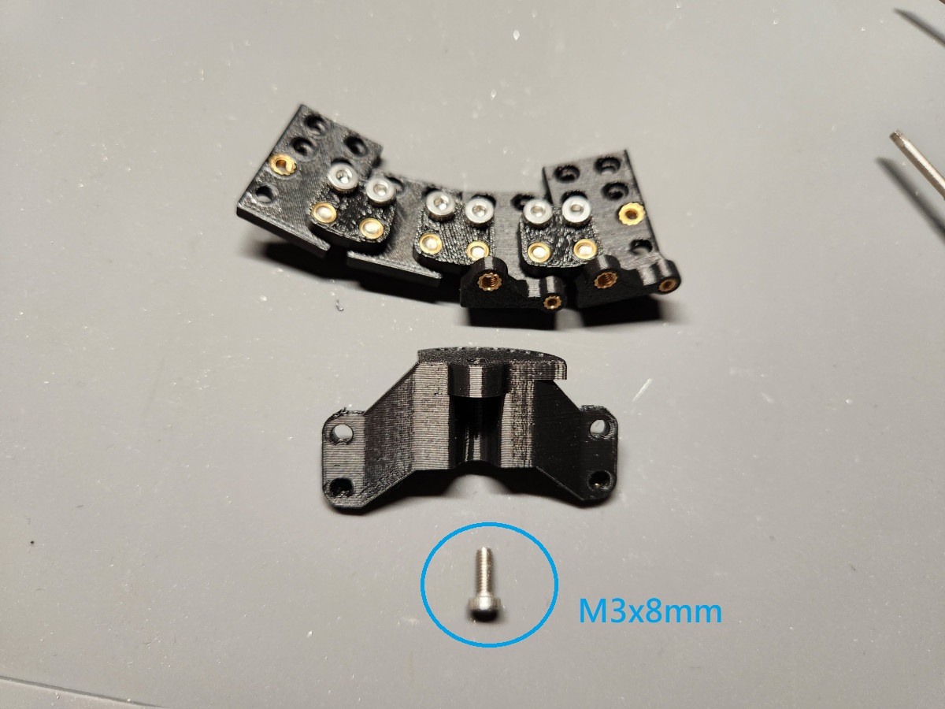
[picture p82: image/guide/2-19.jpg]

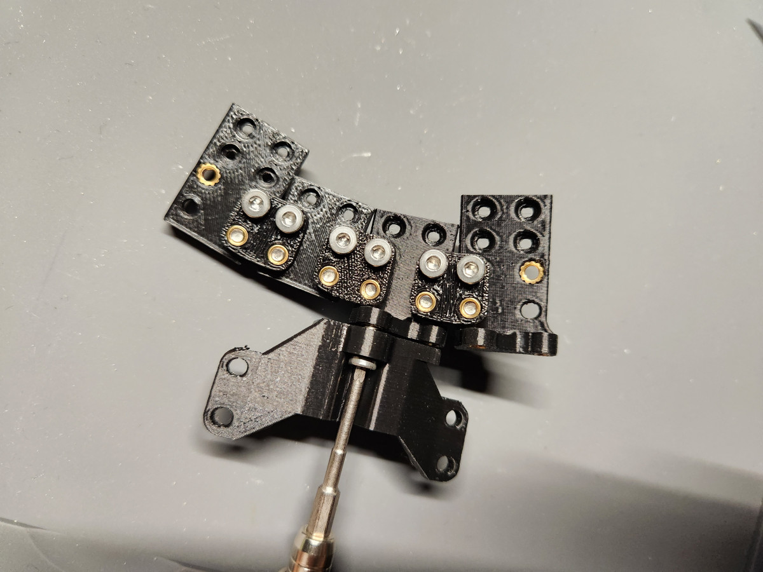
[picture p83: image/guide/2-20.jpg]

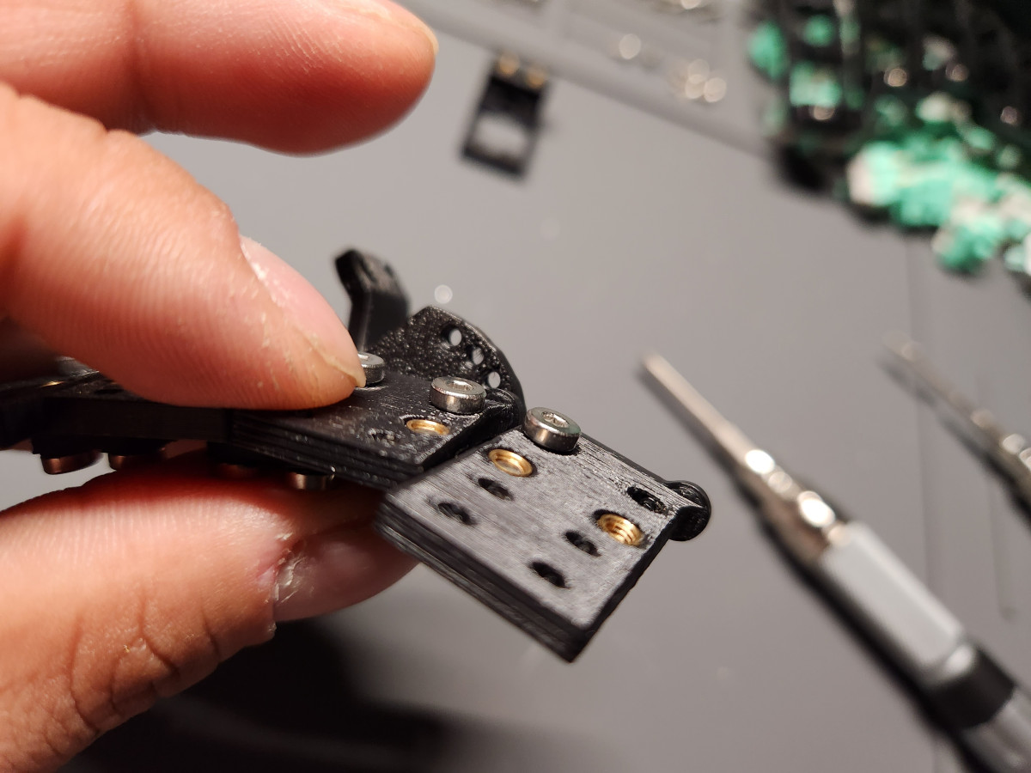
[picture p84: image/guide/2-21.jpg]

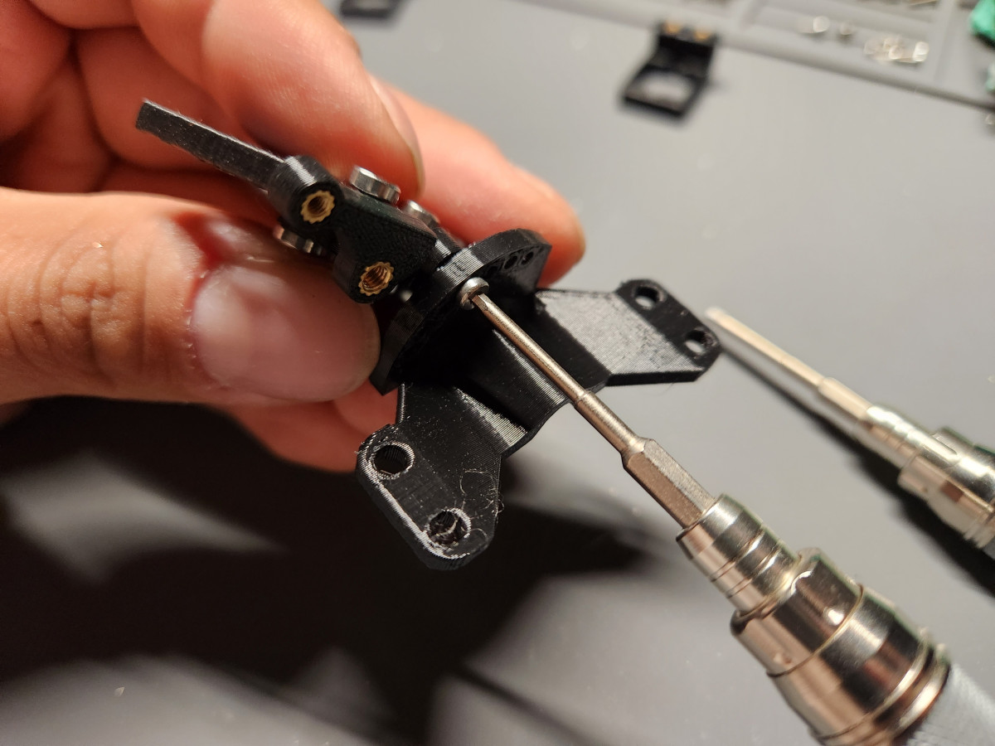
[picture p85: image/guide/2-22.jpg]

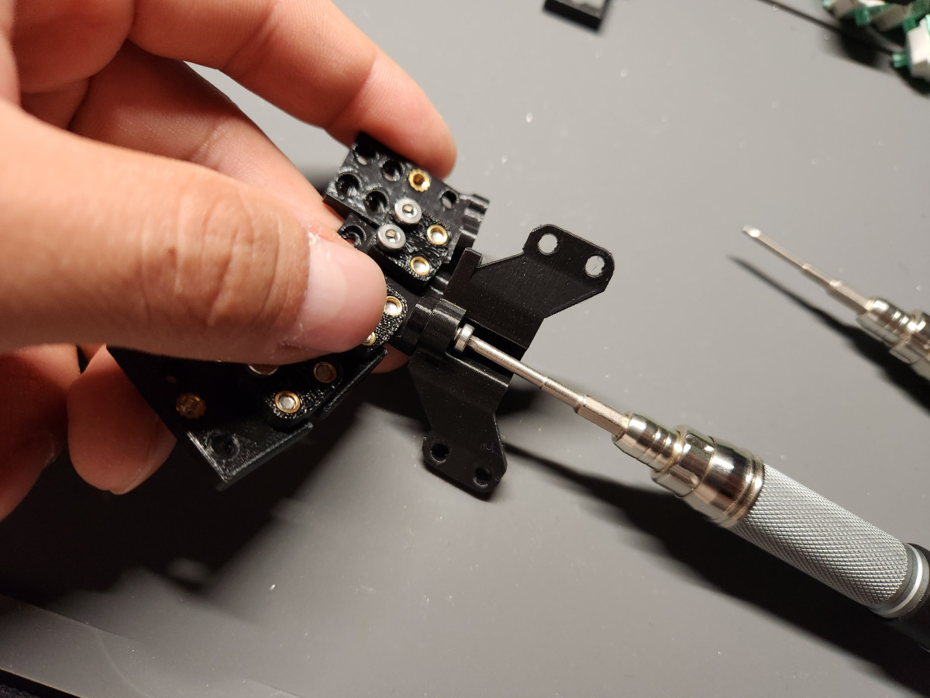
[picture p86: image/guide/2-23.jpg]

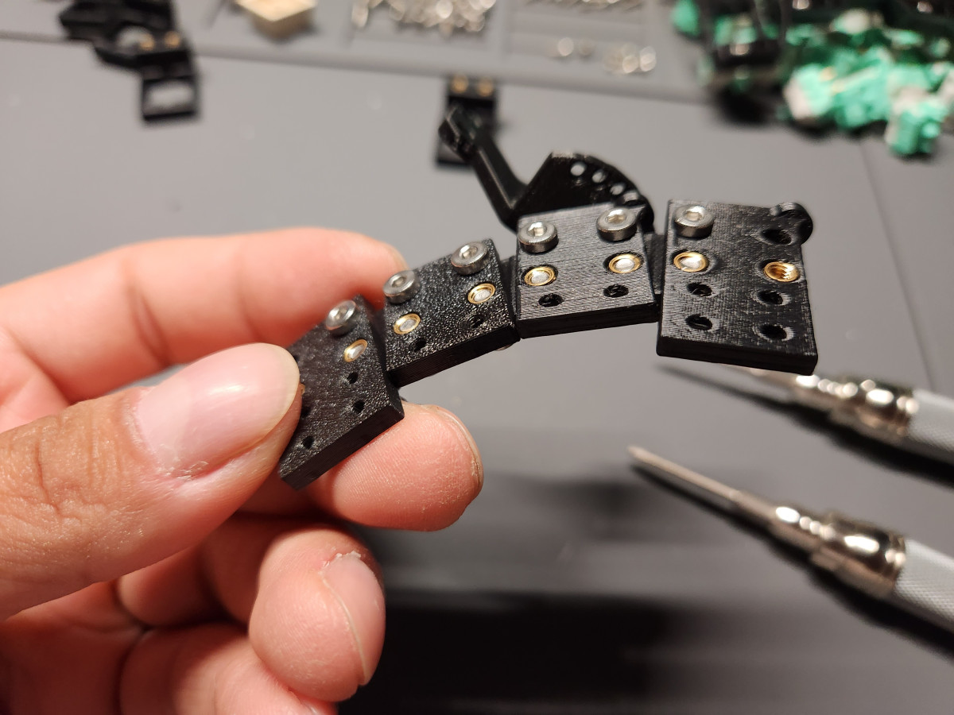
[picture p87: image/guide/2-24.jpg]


- 最後將拇指定位板安裝上去：
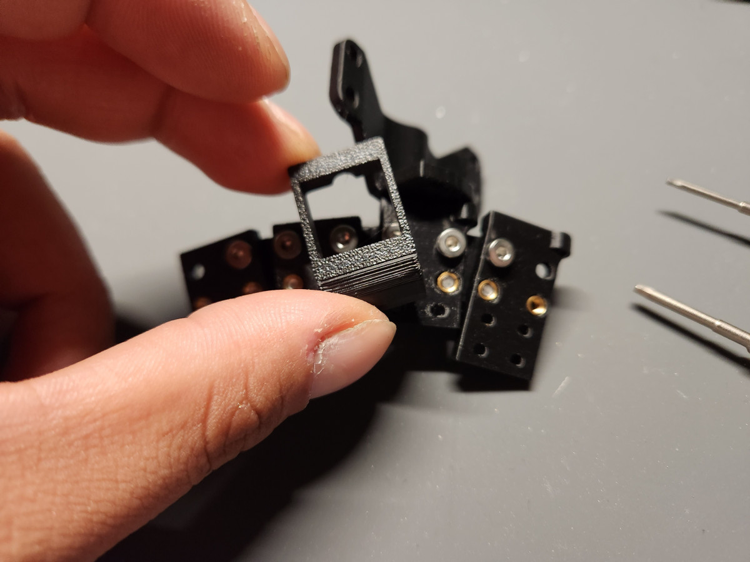
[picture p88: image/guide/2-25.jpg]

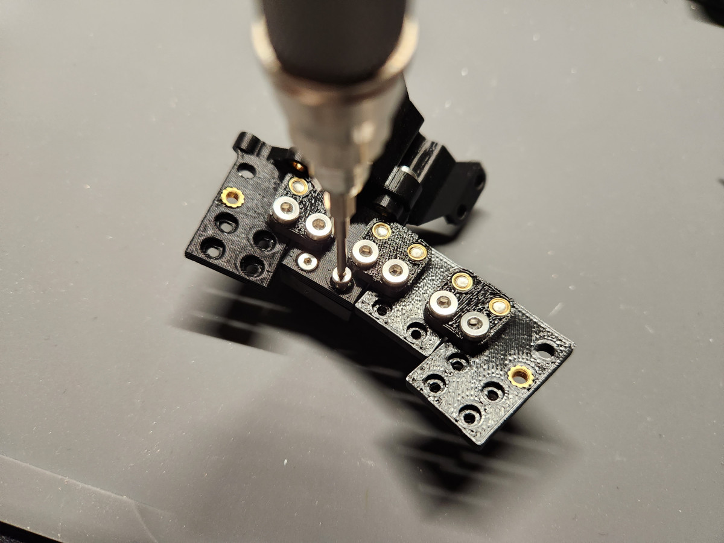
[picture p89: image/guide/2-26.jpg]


- 拇指定位板根據型號A的長板可進行定位板前後6mm微調，根據自己喜好安裝即可：
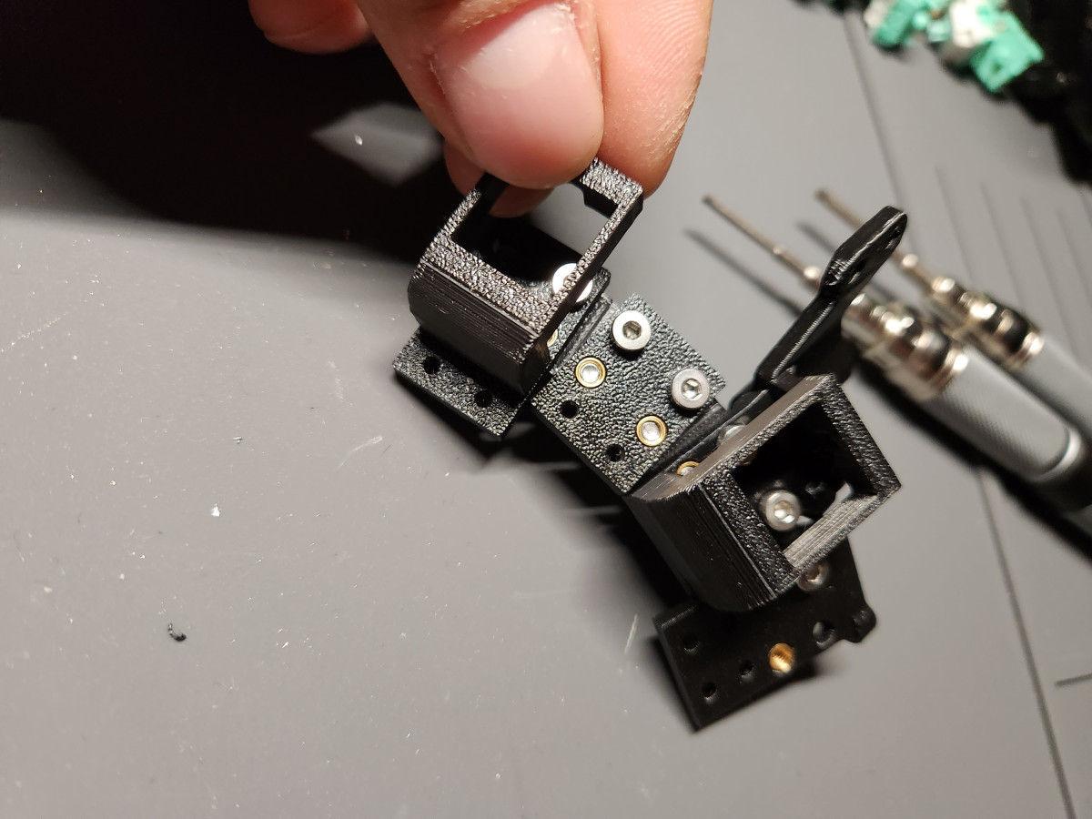
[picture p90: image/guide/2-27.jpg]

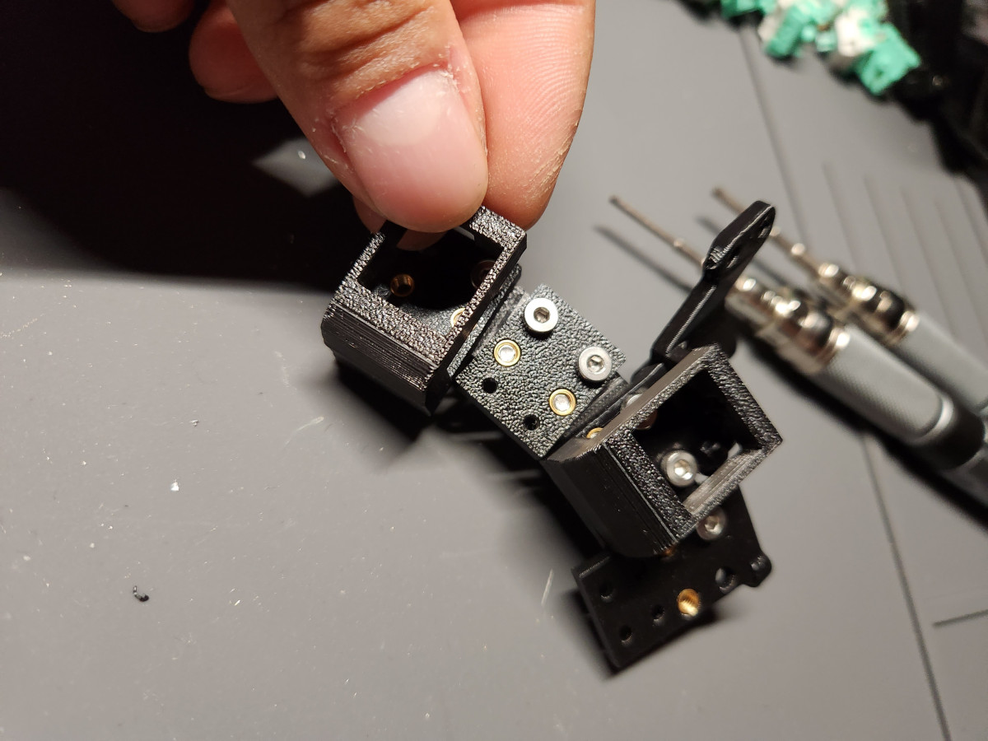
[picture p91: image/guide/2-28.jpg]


- 拇指區安裝完畢：


- 底殼底部雲台座部分先使用防滑腳貼貼在雲台接觸面上，由於PLA材質問題只有單雲台有防滑機制的話會無法穩固鍵盤本體。


- 然後將4x5定位板、拇指區及底殼合併。




- 最後將鍵盤本體安裝在雲台上就完成了。



> **Note**
> 
> 完成外殼後務必先安裝鍵軸及鍵帽測試是不是適合自己，不適合的話再做微調，直到滿意為止。

- 拇指區按鍵數量焊接前先決定好，本篇組裝說明只會解說固定4鍵的拇指區。





- 如果有需要安裝拓展，安裝方式如下：



### （三）配線圖及原理

- 探索者1號使用的是ATmega32U4的MCU，這裡我是使用有實體Bootloader按鈕的Pro Micro做安裝，可以直接省略用針腳短路Reset的燒錄方式。


> **Note**
> 
> 這裡定義MCU帶晶片的那一面為正面、反之為背面，後續解說不會再提及。


> **Warning**
> 
> Pro Micro的部分會使用到RX1、右邊的GND、VCC，用於控制TRRS的訊號傳輸；矩陣部分會使用D4、C6、D7、E6、B4、B5作為Column；F7、B1、B3、B2、B6作為Row。

- Pro Micro針腳腳位示意圖：


> **Warning**
>
> 完整矩陣走線圖務必記下來，後續佈線的時候會一直用到。

> **Note**
>
> 探索者1號使用的Firmware為4x6+4的Keymap，全配列通用一個韌體控制（one firmware controls all），目的為增大鍵盤的改裝自由度；原理為開關ON/OFF的基本道理，這裡不理解沒有關係，之後會在[操作說明書中](manual.md)做解說。

- 3x6、4x6佈線圖：



### （四）單格電路板準備動作

- Dactyl Manuform系列鍵盤最主要使用的是電線連接軸體針腳彼此來建立鍵盤矩陣，但工藝相對來說比較繁瑣及麻煩，因此在設計探索者1號的時候就是以[單格電路板](https://www.pragmatic.com.tw/shop/single-switch-pcb-101#attr=)開發設計，這裡特別感謝[James Sa](https://github.com/jamessa)為了我而設計這塊單格電路板，可以在焊接、熱插拔這兩個選項中做選擇。
- 這裡列出幾種可以作為替代的單格電路板供大家參考：[Amoeba Single PCBs](https://github.com/mtl/keyboard-pcbs)、[MxLEDBit](https://github.com/swanmatch/MxLEDBitPCB)、[PCBabies](https://boardsource.xyz/store/5ecb867c86879c9a0c22dbb6)。

> **Note**
> 
> 在正式焊接之前要特別介紹常用的焊接工具——助焊劑、或是稱為錫膏；探索者1號除了壓製熱壓螺母不會動到錫膏之外，其他地方用量相當大，而且好用。


#### A、貼片二極體

- 首先準備好相應數量的單格電路板，4x6+4會用到56片。


- 簡單說明下單格電路板上焊點及走線。


- 首先我們需要焊接1N1418貼片二級管到單格電路板上，由於貼片式二極管真的太小，我的手機無法使用微距拍攝，這邊借用一下網路上的[商品圖](https://www.alibaba.com/product-detail/Switching-diode-1N4148WT-1N4148-T4-SOD123_60811969627.html)。
 
> **Warning**
> 
> 二極體有分正負極之分，其中有直線的那端為負極，這裡不知道什麼是負極沒有關係，就根據有線的那端作為方向性安裝。


- 依據單格電路板上的方向做安裝。


- 先在二極體焊點其中一邊點上錫。


- 接著使用鑷子對好方向後，簡單溶解焊錫，將二極體的一邊接上去。


- 固定好單邊後，用鑷子輕輕壓住二極體，再用烙鐵點一下錫，完整貼平二極體。


- 最後再固定另一邊就完成了。



#### B、熱插拔座

> **Note**
> 
> 沒有支援熱插拔座的話，可以直接跳到下一步。

- 接著在熱插拔座單邊焊點先上一點錫。


- 接著將熱插拔座固定上去（先上錫的一邊先固定再用另一邊）。





- 將56片都焊接好後，接著進入下一個步驟。


### （五）單格電路板矩陣建立

> **Note**
> 
> 矩陣焊接務必搭配[大步驟（三）](https://github.com/DreaM117er/Explorer-Keyboard-RxCT/blob/main/guide.md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)裡提到的佈線圖，會比較好理解。

- 將單格電路板、軸體、定位板準備好。



- 將鍵軸事先安裝到定位板上，這裡採用的是下燈位。





- 再將單格電路板固定到鍵軸針腳處。



- 將準備好的鍵帽安裝在拓展及拇指按鍵上，目的是不讓它們在焊接時晃動



- 接著準備一定長度的白色矽膠電線，對好焊點至焊點之間的距離後，將它們用小剪刀剪下來。



- 使用剝線鉗將電線的兩端的金屬部分露出。


- 然後用焊錫把焊點先填上，這樣比較方便做電線固定。


- 電線兩端沾上一點錫膏後，用鑷子做輔助，烙鐵加熱其中一邊焊點使其融化後，將電線一端接上去。


- 接著固定另一邊。


- 首先是拓展部分的Column完成。


- 接著是右手鍵盤。


- 雙手的部分。


- Column的部分完工之後，準備紅色電線，用於Row的連接。


- Row的步驟跟Column相同，只是電線長度會稍稍不一樣。


- 首先完成單邊鍵盤Row。


- 再來是雙手（拓展部分的Row會用排線形式做連接，因此這裡只要把主鍵盤的Row先接好即可）。


### （六）鍵盤韌體及主控座

#### A、燒錄鍵盤韌體

- 由於我不是熟悉程式設計的工程師，因此很多東西需要花時間研究... 不過還好，2023.05.06晚上8點左右的時間，支援VIAL改鍵的探索者1號韌體成功編譯出來了，配列如下：


- 預設鍵位第一層～第四層：





> **Note**
> 
> 在組裝說明第三點有提到：全配列使用同一個韌體，這樣的好處是自由度增大，會在[操作說明](manual.md)提及。

- 首先將韌體[下載](https://github.com/DreaM117er/Explorer-Keyboard-RxCT/releases)下來準備好，打開[QMK toolbox](https://github.com/qmk/qmk_toolbox)。


- Local file的位置選定explorerkb_rxct_vial.hex，接著將Auto-Flash勾選起來。


- 將2片Pro Micro（主控、MCU）準備好，單片接上電腦後讓電腦辨識，此時會亮橘紅色燈光。


- 接著按下Bootloader的按鈕將韌體燒錄進Pro Micro裡面。


- 這時的Pro Micro會亮藍色及綠色的燈光。


- 燒錄結束後，右下角會跳出"我們正在設定Explorer Keyboard RxCT"的視窗。



- 最後點開VIAL查看是不是已經辨識到鍵盤。


> **Note**
> 
> 特別留意兩片Pro Micro都要燒錄韌體，且不要使用VIAL事先改按鍵，不然實際上機時左右邊鍵盤不會相互辨識。

#### B、建立主控座

> **Warning**
> 
> 主控座排線的部分會使用到RX1、右邊的GND、VCC，用於控制TRRS的訊號傳輸；矩陣部分會使用D4、C6、D7、E6、B4、B5作為Column；F7、B1、B3、B2、B6作為Row。也就是框起來的pin腳。


- 準備好排針母座，將上圖對應數量的母座用美工刀切下來。



- 接著將排針安裝在主控背面，從正面焊接。





- 完成2片主控後，接著在背面貼上絕緣膠帶。




- 將主控安裝在主控座上。




- 最後將卡扣鎖回去（務必記得雙手主控座都要先完成）。




#### C、連接TRRS座

- 接著準備排針公頭，將2組3pin切下來。


- 準備好烙鐵工作臺、電線、超黏無痕膠帶、TRRS線。


- 首先將TRRS座稍微固定在TRRS線上，用工作臺上的固定夾固定。



- 接著在3個會使用到的針腳上刷上助焊劑。


- 將針腳上沾上一些錫後先放著。



- 接著剪下長度稍長的電線，需要用到6條。



- 用剝線鉗將所有剪下的電線其中一端露出金屬部分，沾上錫膏。



- 接著將電線接在TRRS座上。



- 剪下適量長度的熱縮管。


- 套上電線拉至TRRS針腳處，用熱風槍將熱縮管固定。



- 接著將TRRS座安裝在主控座上。


- 依據[配線圖](https://github.com/DreaM117er/Explorer-Keyboard-RxCT/blob/main/guide.md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)，測量TRRS各針腳需要使用多長長度連接到對應的主控針腳上。




- 把3pin公排針夾上固定夾


> **Warning**
> 
> 這裡特別留意上錫的時間不能超過1秒，排針上的塑料固定口會融化崩解

- 依照TRRS座接電線的方式，在針腳上刷一點錫。




- 熱縮管先套至TRRS座上的電線再進行電線連接的動作。




- 然後將熱縮管固定好。



- 再用美工刀將3pin公排針切開。


- 接著剪下無痕膠帶後貼在TRRS座上。



- 將TRRS座固定在主控座上，最後再將卡扣鎖上。




- 最後將雙手TRRS座上的排針連接到對應的位置。



### （七）、排線

#### A、製作排線 

> **Note**
> 
> 1. 製作排線是需要點細心的手藝，這邊我會儘可能的教大家如何製作。
> 
> 2. 探索者1號最後的安裝步驟都會跟排線有關，第一次做務必做好Column、Row走線使用的電線顏色，這是為了防呆處理，也比較好辨識排線上的針腳是走什麼訊號。
> 
> 3. 特別留意拇指區、拓展的部分，這兩個地方製作的排線會稍稍複雜一點。

- 首先準備好烙鐵工作臺、錫膏、筆刷、紅色電線、白色電線、剝線鉗、小剪刀等工具。


- 排線依據功能連接需求會需要使用公排針或母排針，這邊先以連接底殼跟主控座用排線當作範例。


- 這裡先準備一定長度的白色電線，用於Column；紅色電線用於Row。


- 先製作可直插主控座上的公排針


- 首先將一定長度的白色電線剪下6條備著；紅色電線剪下5條。


- Column會使用到6pin的公排針、Row會用到5pin，先用美工刀切下來備著。


- 這邊先從Row的排針開始做，首先把5pin排針夾在夾子上。


> **Warning**
> 
> 特別留意上錫的時間不能超過1秒，排針上的塑料固定口會融化崩解。

- 在針腳上刷上錫膏後，點上一點錫。



- 接著將電線的一端剝出金屬部分。


- 線頭點一點錫膏後，連接排針。



> **Note**
> 
> 是不是這個感覺跟TRRS座的連接方式很相似？沒錯，原理基本一樣，就差在有沒有將排針切開分離。

- 接著在線頭連接處上熱縮管固定後，會得到一組單邊公排針的排線。


- 接著就將所有主控部分會用到的單邊排線都先做好備著。


#### B、底殼部分

- 接著將Column、Row公排針的部分穿過底殼，接在主控座上。



- 接著用M3x6mm扁頭螺絲固定住主控座。



- 這裡會測量需要多長的排線，首先用手將電線順好，簡單量一個合適的長度後，把不要的部分剪掉。




- 將主控座跟排線先卸下，準備排針母座。


> **Warning**
> 
> 特別留意在接線前要先將熱縮管套上。

- 接著做法跟公排針一樣：夾子夾住排針座、刷錫膏、點錫、剝線、接線。





- 完成所有的排針後，再次安裝主控座至底殼上。





- 排針母座上黏無痕雙面膠，按照先前找到的位置固定住。



- 最後會是這樣的感覺：


#### C、定位板

- 接著我們要將主定位板上連接各個部件的排線建立好，請看下圖配線圖框起來的部分：


> **Note**
> 
> 1. 這個步驟會稍微有些複雜，務必按照順序慢慢看。
> 
> 2. 除非已經決定好自己需要什麼樣的配列，不然請按照組裝說明的方式做安裝。

- 準備好5pin單邊白色公排針2組，先建立主鍵盤Column連接底殼的排線。


- 將排線依序連接到主鍵區上的Column孔位（綠色圈起來的地方）。


- 個人建議可以先從中指的部分開始接，再依序向外做接線。


- 完成後會是這樣的感覺。


- 再來連接Row連接底殼的部分（黃色部分）。


- 最後會是這樣。


- 接著會來進行拓展連接用的排線，4x6配列會使用到5pin的排母。（如果沒有要安裝拓展可跳過這個步驟）


- 為什麼會用到5pin？大家可以看一下佈線圖，連接拖展的部分除了4個Row之外，還有一條線是接在Column上。


- 接著就是製作連接4條紅色電線跟1條白色電線的排針母座。



- 完成母排針後，Column連接底殼的部分會使用到公排針。


- 最後將紅色部分依序連接到拓展會用到的Row孔上。


- 完成後會是這樣。


- 依序這個原理，最後一個步驟就是將連接拇指區的排線做好。


- 這邊會用到4條白色電線跟1條紅色電線，跟拓展一樣使用5pin排針母座建立單邊排線。



- 接著將白色的部分分別接在Column0～3的位置上（藍色圈起來的部分）。


- 連接拇指區的排線特別留意要從中指區下方的洞口露出，務必對好中指區的長度進行裁切。


- 裁切好電線長度後開始接線。


#### D、拓展板

- 接著再準備製作拓展用的排針公排線。



- 這邊可以線將排針接在主鍵盤上進行測量再進行電線的裁切。


- 完成後會是這樣：


- 接著將拓展底板線固定上去後，暫時放一邊。



### （八）主鍵盤組裝

- 接著按照佈線圖上標示的走線安裝排線，特別留意顏色的部分，這是比較特殊的排線走法，務必不要接錯線。


- 左手鍵盤：



- 右手鍵盤：



- 接著開始接左手鍵盤的線。




- 蓋上底板後，鎖上螺絲就完成了。


- 再來接右手鍵盤的線。



- 一樣鎖上螺絲。



- 最後會是這樣的感覺。


- 到這邊已經可以把TRRS線接上再接電腦測試按鍵，但不要將VIAL中的Matrix Tester打開測試，請使用[Keyboard Test Utility](https://keyboard-test-utility.en.lo4d.com/windows)跟預設鍵位做測試。


### （九）拇指區及最後組裝

#### A、固定鍵位

- 這裡會演示2種不同拇指區的安裝方式，先演示預設鍵位的4鍵拇指按鍵。


> **Note**
> 
> 這邊會需要用焊錫填上Row及Col的其中一個孔位，根據自己的判斷方便拉線即可。

- 再將紅色電線量好按鍵左右距離，並將它們接在一起。



- 最後拉1條較長的電線，用於連接主鍵盤。


- 接著將每顆按鍵的Column都接上。


- 再來將5條電線依序接在5pin的公排針上（不要忘記先套熱縮管）。


- 最後將紅色Row跟白色Column的公排針切開來分離。


- 排針做好之後就可以將拇指區按照喜歡的角度裝回去。


- 按照顏色及對應的Column將排線連接主鍵盤。



- 接著將基座的4顆螺絲鎖上底殼。


- 這樣鍵盤就完成了。


#### B、可插拔按鍵

> **Note**
>
> 可插拔按鍵是我在建立組裝說明的時候想到的，可根據自己的需求決定是不是要用這個方式做安裝，好處是可以不用動烙鐵就可以快速插拔變更鍵盤的拇指按鍵數量。

- 首先準備好4pin的母排針座，上頭先上一些錫。


- 接著準備一條電線，將裡面的線芯用旋轉的方式抽出來，接著在線芯上抹上錫膏，用錫先將它們集成一束。


- 將線芯用焊錫固定在4個針腳上。



- 完成後再接1條紅色的電線在外側一端針腳上，用熱縮管套上。


- 可以繞一圈修剪一下長度後，把公排針接上去。


- 接著再將排針母座用膠固定在主鍵盤上的排針上（這裡務必對好針腳前後左右要對齊）。


- 再來將公排針接在連接主鍵盤的母排針上。


- 最後用絕緣膠將排針捆起來就完成前置動作。


- 接著將拇指按鍵上的Row跟Column各接、拉1條等長的線出來。


- 完成後將按鍵線固定在底板，再接到底殼上。




- 將電線裁切好後，將按鍵卸下，準備接2pin公排針。



- 4顆按鍵完成後，按照排線的長度依序對好底板位置，再將按鍵安裝回去。




- 接著將各個按鍵的排線依序接上排針母座。



- 稍微旋轉一下將電線集成一束。


- 最後將基座螺絲鎖上就完成了。



#### C、最後安裝

- 再來將完成安裝的左右手接在雲台上，接上TRRS線後接電腦。


- 測試按鍵、安裝鍵帽後就完成了。


> **Note**
> 
> 接著請到[操作說明](manual.md)那邊瞭解這把鍵盤的特殊操作模式。

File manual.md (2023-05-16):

# 操作說明

> **Warning**
> 
> 務必先將鍵盤[安裝完畢](guide.md)後再來看操作說明。

## （一）安裝雲台腳架

### A、雲台安裝需求

> **Warning**
>
> 探索者1號是完全支援雲台的分離式鍵盤，沒有其他的安裝方式，但也不是什麼雲台配件都可以使用，這裡我會列出以下幾點安裝雲台時的要求：
>  - 底板面積要大。
>  - 底座要比單手鍵盤本體重量要重。

> **Note**
>
> 建議配置[Arca快拆系統](https://www.google.com.tw/search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)：
>   - 留意整體大小不要衝突主控座，特別是有線TRRS座主控座的安裝。
>   - 穩固鍵盤本體。
>   - 快速拆卸雲台，方便直接調整底座的角度。

### B、雲台安裝步驟

> **Warning**
>
> 以下說明並非廠商廣告，請當作參考閱讀。

- 我使用的雲台配件如下，[SmallRig](https://www.smallrig.com/)：[1092](https://www.smallrig.com/cool-cheese-plate-v3-multi-purpose-mounting-plate-1092.html)、[2065](https://www.smallrig.com/smallrig-articulating-arm-5-5-inches-2065.html)，[Falcam](https://www.falcam.com.cn/)：[F38 series 2400（2465）](https://www.falcam.com.cn/falcam-f38-pd-quick-release-plate-2465_p64.html)、[2401](https://www.falcam.com.cn/falcam-f38-anti-deflection-quick-release-plate-2401_p61.html)。


- 首先安裝單邊魔術手臂到洞洞板的位置上。



- 再將魔術手臂角度稍微調整一下。


- 將魔術手臂鎖緊固定好。


- 將Arca快拆系統母座安裝上去。


- 再將另一支手臂安裝好。


- 接著將Arca子板安裝在鍵盤雲台上。


- 螺絲鎖緊。


- 接著就可將鍵盤安裝在底座上了。


- 完成會是這樣的感覺：


- 最後再調整魔術手臂的角度，選定一個喜歡的角度後再將魔術手臂固定好。


- 接上TRRS線。


- 再將鍵盤連接到電腦。


- 完成！


## （二）排線原理及VIAL QMK按鍵設定

### 排線原理

> **Note**
>
> 閱讀到操作說明這邊的讀者，假如你/妳是按照標準的排線安裝流程組裝鍵盤的話，這邊會告訴你這樣做的原理：


> **Note**
>
> 除了將矩陣用排針的形式拓展之外，這樣做的原理還可以當作另一種開關的形式。打個比方：我要在4x5主配列上做1列的拓展，就將拓展上的排線接上去，鍵盤就會立即辨識。在還沒有接上拓展排線時，鍵盤拓展為Off，接上的時候為On。

> **Note**
>
> 也就是說，你要使用拓展，就將拓展的排線接上去，底殼螺絲鎖上，這樣就可以無痛升級。

### VIAL按鍵設定

> **Warning**
>
> 探索者1號不限配列，統一使用一個韌體，這樣設計的原因為增加鍵盤的可玩性，接著來說明VIAL要如何改按鍵。

- 首先進入VIAL，探索者的鍵盤配列會長這樣：


- 簡單介紹一下物理層面控制的位置，所有框起來的部分是可依據現有配列去做更動的，沒有用到那顆按鍵或是沒有那顆（排）按鍵，就不要在那個位置設定鍵位，即使你設定了，你也沒辦法讓電腦辨識。


- 打個比方，作者本人的配列屬於3x6+3，合計42鍵的鍵位，因此在VIAL上，我可以設定鍵位的地方如下：


> **Warning**
>
> 沒有被紅色區塊框起來的地方就算有設定鍵位也沒辦法按，這點大家在改按鍵的時候特別注意。

## （三）基礎配列

> **Note**
>
> 探索者1號在設計的時候是以同一個拇指區基座為基底設計，有3x5及4x5可以選擇。

### A、3x5配列



### B、4x5配列



### C、3x6配列



### D、4x6配列



## （四）特殊配列

> **Note**
>
> 以下配列都是可以運行且正常使用的，不用懷疑。

### A、標準VIAL預設配列



### B、左手4x5+3、右手3x6+3



### C、左手3x6+3、右手標準VIAL配列



## （五）拇指區

> **Warning**
>
> 拇指區會根據是否為直接焊接Row或是可插拔按鍵的安裝形式有不同的變更模式。

> **Note**
>
> 操作說明這裡提到的拇指區為已經安裝完畢的鍵盤。

### A、調整角度

- 首先將拇指區基座螺絲卸下。



- 再將排線跟主鍵盤分離，卸下拇指區。


- 接著將拇指基座上的螺絲卸下，將拇指底板跟基座分離。



> **Note**
>
> 基座部分有0～90度可以調整拇指區，合計7個檔位可以選擇。


- 選好想要微調的角度後，再將螺絲鎖回去。


- 再將排線對好順序接回去。


- 完成！


### B、定位板挪移

> **Warning**
>
> 直接焊接Row拇指區的話，唯一可以變更的只有底板樣式，請往下看操作說明。

- 按照調整角度拆卸方式，將拇指區卸下。


- 型號A的長底板可以將拇指定位板做前後挪移，這裡先示範移動空白鍵。


- 首先將空白鍵底板上的螺絲卸下。


- 將空白鍵移動至要變更的螺絲孔位。


- 再將螺絲鎖回去。


- 接著將排線接上主鍵盤後，再將拇指區基座裝回去。


- 效果會是這樣。


> **Note**
>
> 這是只有變更單鍵的底板，如果全部固定的按鍵都要變更底板的話，就將所有的底板拆下來，把底板變更完畢後再裝回去。

### C、變更底板

> **Warning**
>
> 只有AA及AB底板可以連接基座，這裡再強調一次。


- 首先將拇指區跟基座卸下。


- 接著將基座調整到另一片可連接基座的底板上。


- 將基座安裝上去。



- 接著再將排線接在主鍵盤上。



- 最後將拇指基座安裝回去。


- 效果圖：


- 雙手對比：


### D、變更按鍵數量

> **Warning**
>
> 直接焊接Row拇指區的話，需要動用電烙鐵才可變更按鍵數量。


> **Note**
>
> 可插拔按鍵才能直接變更按鍵數量，請下拉閱讀操作說明。

- 首先將拇指區跟基座卸下。


- 接著來示範將這顆最內側的按鍵卸掉。


- 將最內側按鍵下方的螺絲卸下，分離按鍵。


- 再將隔壁的按鍵也卸下。


- 再來把連接器上頭的固定螺絲解下，分離底板。



- 接著把卸除的按鍵鎖回去。


- 最後把調整好的拇指按鍵接上基座。


- 依據配線圖將最外側按鍵的排線接回去。



- 效果會是這樣，排線會少一條。


- 將基座安裝回去就完成了。


- 效果會是這樣：


- 雙手鍵盤對比。


## （六）結語

- 如果真的有人組完鍵盤並且閱讀到這裡，恭喜你/妳獲得一把自由度極高的分離式鍵盤，喜歡它的話，可以將它分享出去。
- 如果有人組裝好願意分享照片給我的話，可以用任何方式聯繫我，我會將鍵盤的美照放在下方展示給大家知道。

> **Note**
>
> 最後最後，我想告訴大家，我把改裝的自由度給了你，讓你去探索它，這就是為什麼我將它命名為探索者，希望你能愛上鍵盤，玩出新花樣。
>
> 謝謝大家。

## （七）照片展示區

> **Note**
>
> 待更新。
